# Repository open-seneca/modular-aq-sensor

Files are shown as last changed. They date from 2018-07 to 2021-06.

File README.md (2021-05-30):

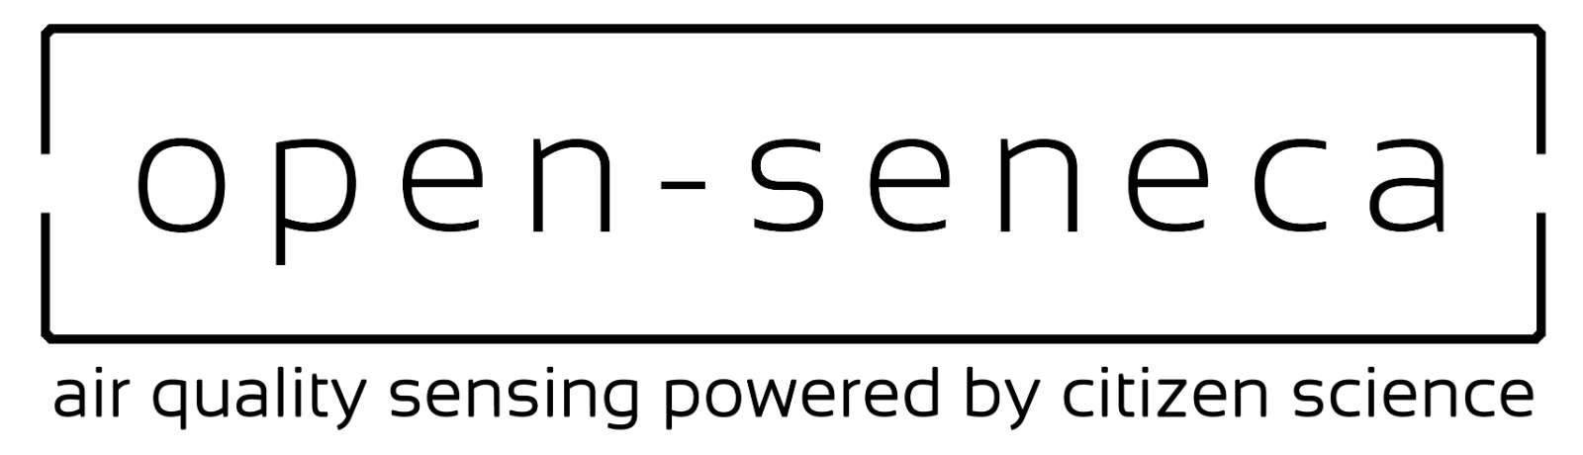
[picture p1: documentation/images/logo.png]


| PCB version | Code version | Name | Pilot date | Lifecycle |
| :---: | :---: | :---: | :---: | :---: |
| v3 | v10 | Europe 21 | current | in production |
| v2 | v8/v9 | Kenya 20 | Mar-20 | in stock |
| v1 | v7 | Argentina 19 | May-19 | discontinued |
| v0 | v4 | CamBike sensor | Aug-18 | discontinued |

Please also refer to our current, smaller, and all-integrated air quality sensor kit which is also open-source on Github: 
https://github.com/open-seneca/integrated-aq-sensor

If you already have a sensor and want to upload and visualise your data you can create an account here:
http://app.open-seneca.org

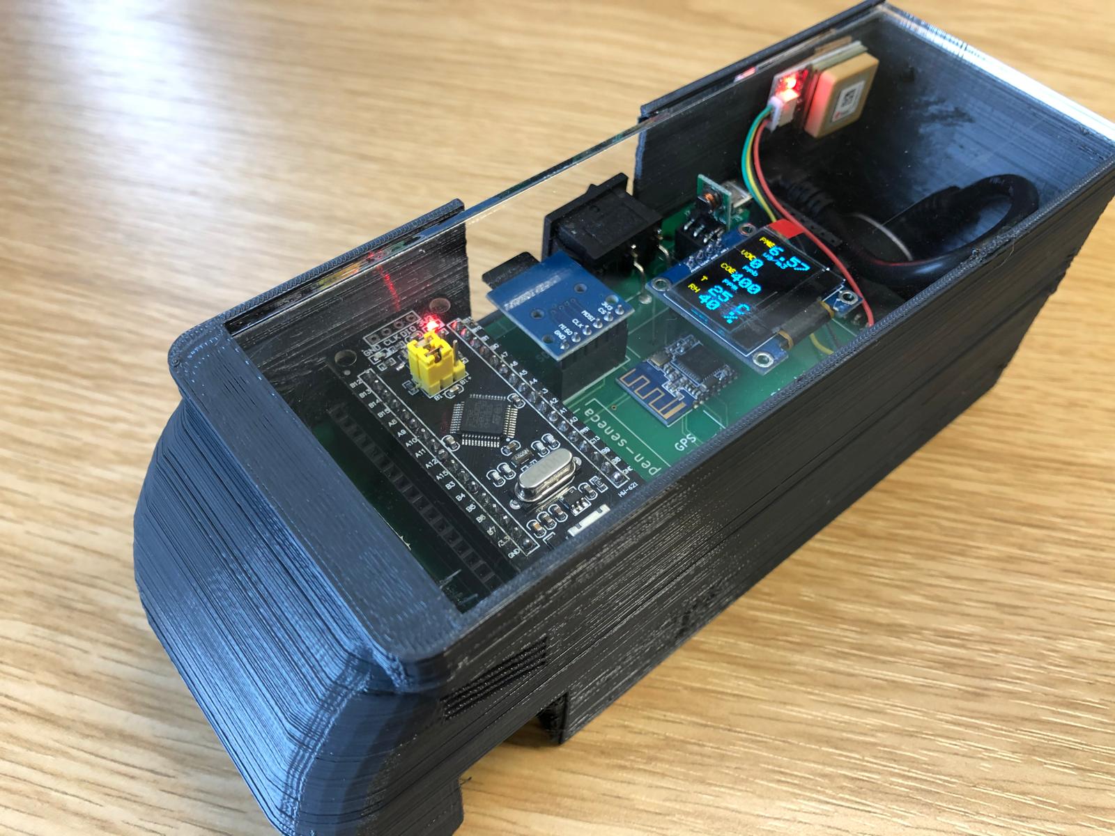
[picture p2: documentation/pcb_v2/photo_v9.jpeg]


If you have built your kit and want to flash the code to the Black Pill board, here is how:

a) Wiring and onboard jumpers:
- RX on the USB2TTL adapter to PA9, TX to PA10, GND to G, 3.3V to V3
- jumper B0+ to center pin, B1- to center pin

b) To flash the code:
- install Arduino Due in IDE board manager
- put Arduino_STM32 library (from the "hardware" folder in this repo) in "My Documents/Arduino/hardware" (Note: if the hardware folder doesn't exist you will need to create it)
- do the same for the content of the "library" folder in this repo
- start Arduino IDE and open the latest bp_vX from this repository
- under "Tools -> Board" select "Generic STM32F103C series"
- under "Tools -> Upload method" select Serial
- press reset button on the Black Pill to enter its flash mode
- click "Upload" to flash your code

c) To execute the code:
- after flashing code should run
- plug both header pins on low (B1- should be low already if your followed the steps correctly, move other jumper to B0-)
- the board will now keep its flash memory, every reset will restart execution

We are an open-source project, please feel free to extend and improve our code, just post a commit!

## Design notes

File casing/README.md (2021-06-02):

- v8 box fits the ublox GPS which has been distribuetd in Nairobi 2020 on motorbikes
- v9 3d-printed enclosure fits the modular SIM868 GSM/GPS module (display visible) which has only been used for demonstration purposes

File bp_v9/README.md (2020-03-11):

## v9 discontinues support for ublox GPS but SIM868 is now supported (GPS and GSM). For ublox GPS please flash v8

## If you experience compilation errors with v9, please check you have the TinyGSM library from this repository and acticate the 128kB memory option for the STM32 in the Arduino IDE (under 'Tools').

### Features
- SIM868 GSM wireless transmission
- HM10 Bluetooth transmission (not yet implemented in code)
- SGP30 TVOC / eCO2 sensor
- SHT31 Humidity / Temparature sensor
- SPS30 Particulate matter sensor
- Connector for UBLOX GPS
- Micro USB power plug
- 128x64 i2c OLED display

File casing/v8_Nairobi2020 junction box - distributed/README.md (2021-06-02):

# This enclosure requires a laser-cut piece (see dwg above), a USB power bank, and a junction box (examples below).

SIM868 does not fit box, use u-blox.

Plastic Electronic Project Box 158 x 90 x 60mm Junction Enclosure Case Box Waterproof w Clear Cover



Aibocn Slim Power Bank 6700mAh Portable Charger 4.3 x 1.2 x 1 inches size



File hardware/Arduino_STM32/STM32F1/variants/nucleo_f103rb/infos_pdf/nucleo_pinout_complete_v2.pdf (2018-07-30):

## left

## side

remapable | default function | Arduino | Name Pin | | Pin Name | | Arduino | default function | remapable
| TX Serial2* | D31 | PC10 | 1 | 2 | PC11 | D44 | RX Serial2*
| SDIO_CK | | PC12 | 3 | 4 | PD2 | D30 | TIM3_ETR
| | | VDD | 5 | 6 | E5V
| | | Boot0 | 7 | 8 | GND | GND
| | | NC | 9 | 10 | NC | NC
| | | NC | 11 | 12 | IORef | IoRef
| SWDIO | D41 | PA13 | 13 | 14 | RST | RST
| SWCKL | D42 | PA14 | 15 | 16 | 3,3V | 3,3V
TIM2_CH1_ETR/SPI1_SS | JTDI | D43 | PA15 | 17 | 18 | 5V | 5V
| | | GND | 19 | 20 | GND | GND
| I2C1_SDA/TIM4_CH2 | D22 | PB7 | 21 | 22 | GND | GND
| User Button | D27 | PC13 | 23 | 24 | Vin | Vin
| 32khz! | D28 | PC14 | 25 | 26 | NC
| 32khz! | D29 | PC15 | 27 | 28 | PA0 | A0/D16 | ADC12_IN0/TIM2_CH1_ETR
| OSC** | | PD0 | 29 | 30 | PA1 | A1/D17 | ADC12_IN1/TIM2_CH2
| OSC** | | PD1 | 31 | 32 | PA4 | A2/D18 | SPI1_SS/ADC12_IN4
| | | Vbat | 33 | 34 | PB0 | A3/D19 | ADC12_IN8/TIM3_CH3 | TIM1_CH2N
| ADC12_IN12 | D23 | PC2 | 35 | 36 | PC1 | A4/D20 | ADC12_IN11
| ADC12_IN13 | D24 | PC3 | 37 | 38 | PC0 | A5/D21 | ADC12_IN10

## right

## side

remapable | default function | Arduino | Name Pin | | Pin | Name | Arduino | default function | remapable
TIM3_CH4 | | D40 | PC9 | 1 | 2 | PC8 | D39 | | TIM3_CH3
I2C1_SCL | TIM4_CH3 | D15 | PB8 | 3 | 4 | PC6 | D38 | | TIM3_CH1
I2C1_SDA | TIM4_CH4 | D14 | PB9 | 5 | 6 | PC5 | D26 | ADC12_IN15
| | VDD | AVDD | 7 | 8 | U5V
| | GND | GND | 9 | 10 | NC
| LED/SPI1_SCK/ADC12_IN5 | D13 | PA5 | 11 | 12 | PA12 | D45 | USBDP TIM1_ETR
TIM1_BKIN | SPI1_MISO/ADC12_IN6/TIM3_CH1 | D12 | PA6 | 13 | 14 | PA11 | D33 | TIM1_CH4
TIM1_CH1N | SPI1_MOSI/ADC12_IN7/TIM3_CH2 | D11 | PA7 | 15 | 16 | PB12 | D34 | SPI2_SS/I2C2_SMBAl/TIM1_BKIN
| I2C1_SCL/TIM4_CH1 | D10 | PB6 | 17 | 18 | PB11 | | I2C2_SDA | TIM2_CH4

TIM3_CH2 | | D9 | PC7 | 19 | 20 | GND
| TX Serial/TIM1_CH2 | D8 | PA9 | 21 | 22 | PB2 | D46 | Boot1
| TIM1_CH1/MCO | D7 | PA8 | 23 | 24 | PB1 | D32 | ADC12_IN9/TIM3_CH4 | TIM1_CH3N
TIM2_CH3 | I2C2_SCL | D6 | PB10 | 25 | 26 | PB15 | D37 | SPI2_MOSI/TIM1_CH3N
TIM3_CH1/SPI1_MISO | | D5 | PB4 | 27 | 28 | PB14 | D36 | SPI2_MISO/TIM1_CH2N
/SPI1_MOSI TIM3_CH2 | I2C1_SMBAl | D4 | PB5 | 29 | 30 | PB13 | D35 | SPI2_SCK/TIM1_CH1N
/SPI1_SCK TIM2_CH2 | RX Serial /SWO** | D3 | PB3 | 31 | 32 | AGND
| RX Serial/TIM1_CH3 | D2 | PA10 | 33 | 34 | PC4 | D25 | ADC12_IN14
use desolder jumper for | TX Serial1**/ADC12_IN2/TIM2_CH3 | D1 | PA2 | 35 | 36 | NC
desolder jumper for use | RX Serial1**/ADC12_IN3/TIM2_CH4 | D0 | PA3 | 37 | 38 | NC

*SW

remapped | 5V
Tolerant | Arduino
Header

### **solder

mod | | Arduino
pin

NR
!

### not

in

use | Dxx | save
to

use?

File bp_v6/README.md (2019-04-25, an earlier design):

## Important: bp_v6 is our new Kenya prototype and currently not compatible with the old PCB on which this GihHub documentation is based on. This is a work in progress.

### New features
- SIM800L GSM wireless transmission
- HM10 Bluetooth transmission (not yet implemented in code)
- SHT31 Humidity / Temparature sensor
- SPS30 Particulate matter sensor
- Connector for UBLOX GPS
- Micro USB power plug

### Discontinued functions
- Accelerometer / Gyroscope
- LoRa wireless transmission

The measured power draw is around 70-90mA (while GSM is not trasmitting) at 5V supply, ~0.4W.
With a 10.000mAh powerbank you can keep the sensor running for about 5 days constantly (ideal conditions).

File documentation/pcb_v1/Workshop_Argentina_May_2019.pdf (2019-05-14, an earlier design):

# WORKSHOP ARGENTINA

## 1.0 MATERIALS AND COMPONENTS

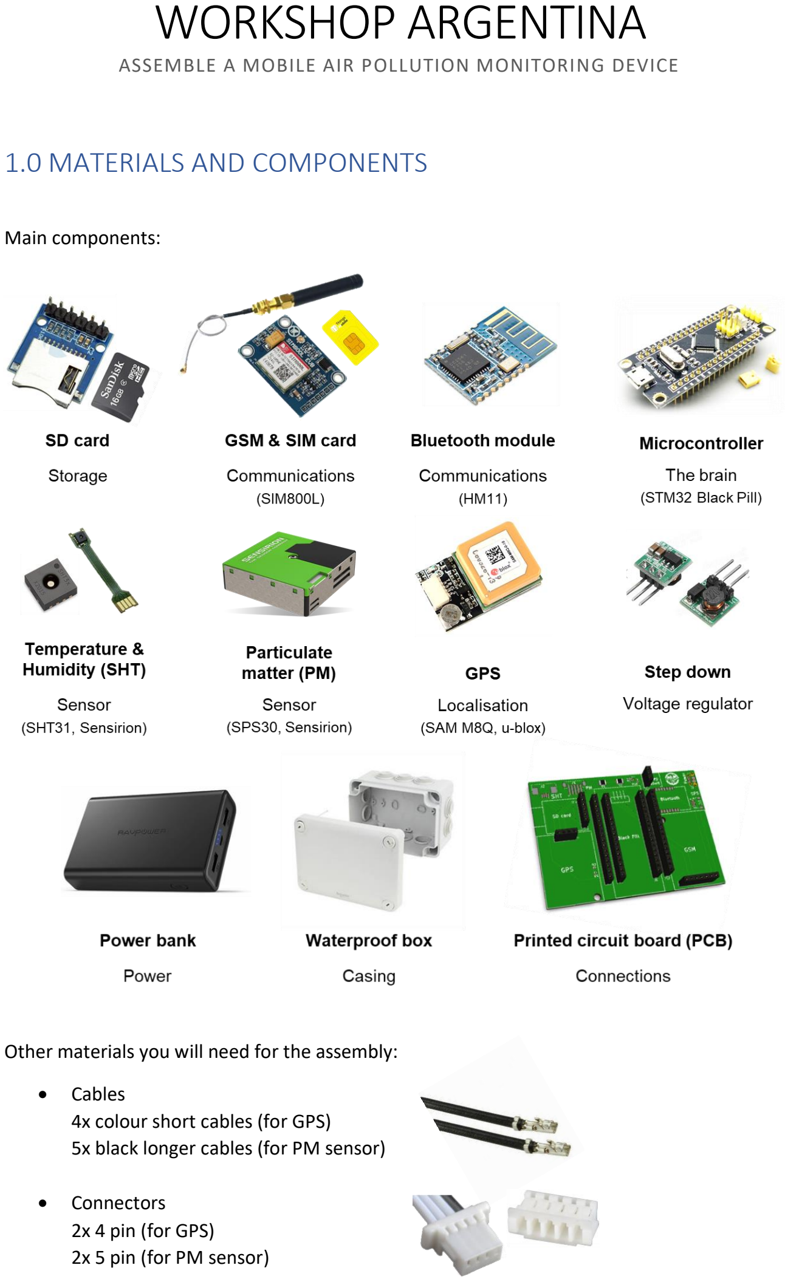
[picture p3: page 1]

ASSEMBLE A MOBILE AIR POLLUTION MONITORING DEVICE

Main components:

Other materials you will need for the assembly:

- Cables
4x colour short cables (for GPS)
5x black longer cables (for PM sensor)
- Connectors
2x 4 pin (for GPS)
2x 5 pin (for PM sensor)

- Fixing materials
Foam
Velcro
Cable ties

## 2.0 ASSEMBLY

1. Have a look to the printed circuit board (PCB). You should see the name of each of the components next to the place where they should be plugged in, either directly or through a connector.
Ask if you have any doubts about which component is which or how to connect them!

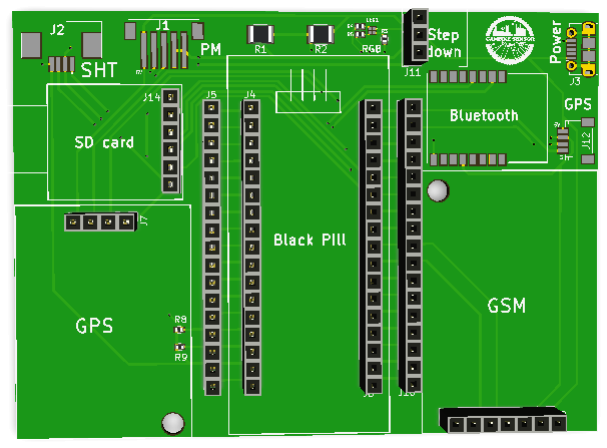
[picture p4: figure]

2. Start plugging the components that have pins into the black pin sockets. You should plug in:
a) the Black Pill microcontroller (check in which direction following the drawing on the PCB!)
b) the GSM module
c) the step-down voltage regulator
d) the SD card module

The only module that is not plugged in is the GPS. Don’t forget to put the SD card in the SD card module and the SIM card in the GSM module! Plug in the GSM antenna as well.

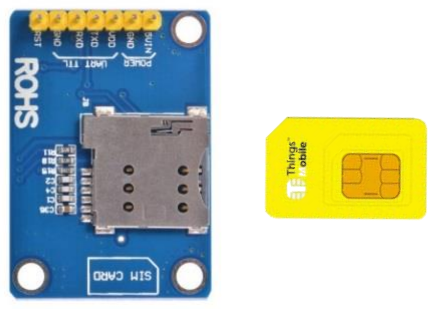
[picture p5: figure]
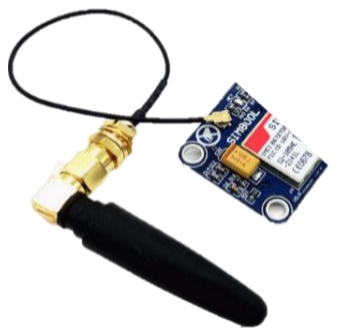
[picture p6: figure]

3. Prepare the connectors for the GPS and the PM sensors:

Connecting the GPS

Plug the white connector into the GPS and then plug the red cable into the connector where it says 5V. You should feel a “click” when the red cable is properly connected. Make sure you plug the cable in the connector in the correct orientation- the small metal protrusion should be aligned with the narrow end of the white connector, as indicated by the green arrows in the diagram. If in doubt, ask to check before plugging it in!

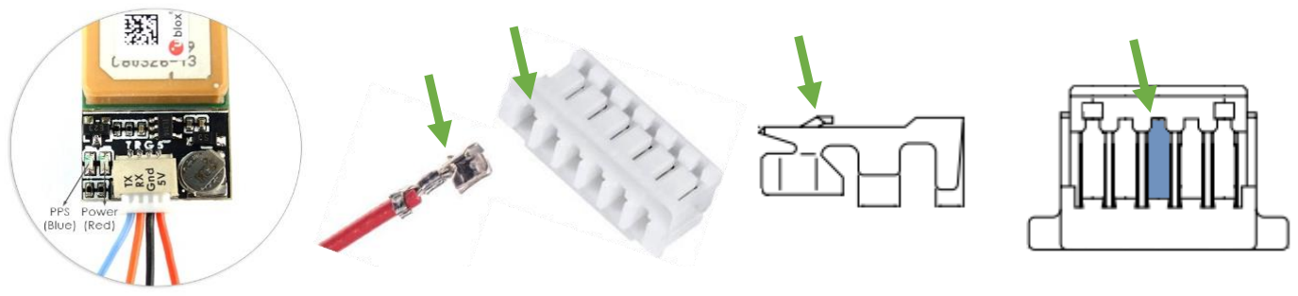
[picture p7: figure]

Do the same at the other end of the cables, plugging the second white connector into the PCB board first and then plugging the red cable in the side of the connector where 5V is written on the board, as shown below.

Plug the rest of the cables into the connectors, following the same order: black for ground (GND) and two colours of your choice for the communication pins (TX and RX).

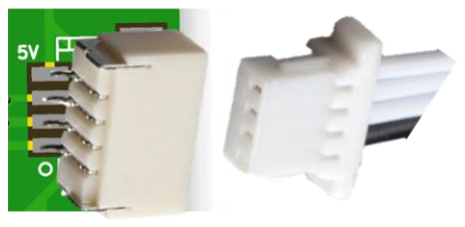
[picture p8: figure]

Connecting the PM sensor

Following the same procedure as for the GPS, plug the white 5 pin connector to the PM sensor. Pin 1 (to the left) is the 5V pin. Connect the cable and plug it to connector on the PCB, where 5V is written on the board. Then follow the same order for the rest.

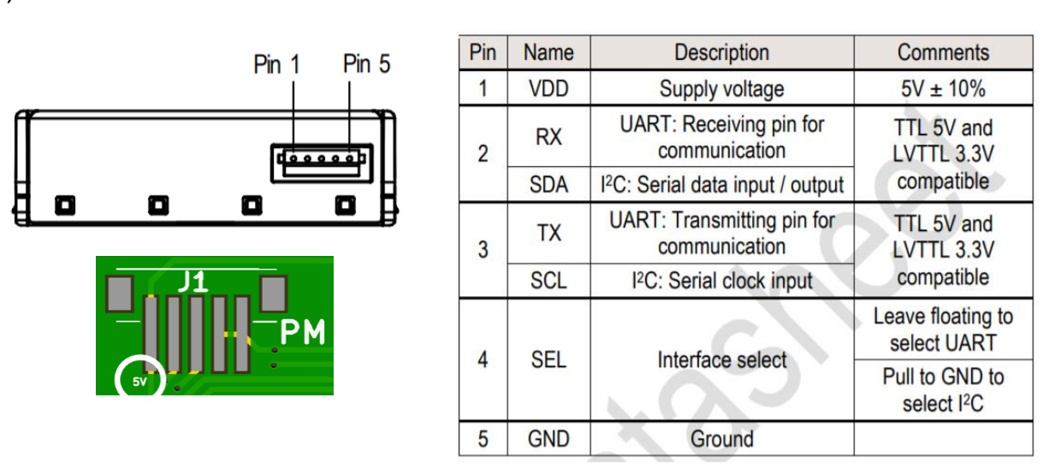
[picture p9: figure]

Datasheet of Sensirion SPS30 PM sensor

4. Connect the temperature and humidity sensor:

Slide the black part of the connector out and clip the humidity sensor in it with the pads looking up. Then reinsert the black connector so the pads are held in place.

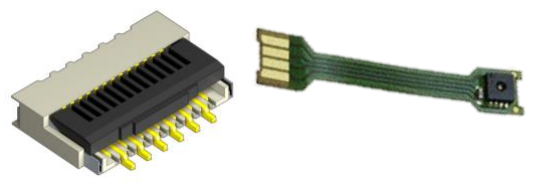
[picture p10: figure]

5. Plug in the power bank using the micro USB cable.
6. Open box and place components inside.

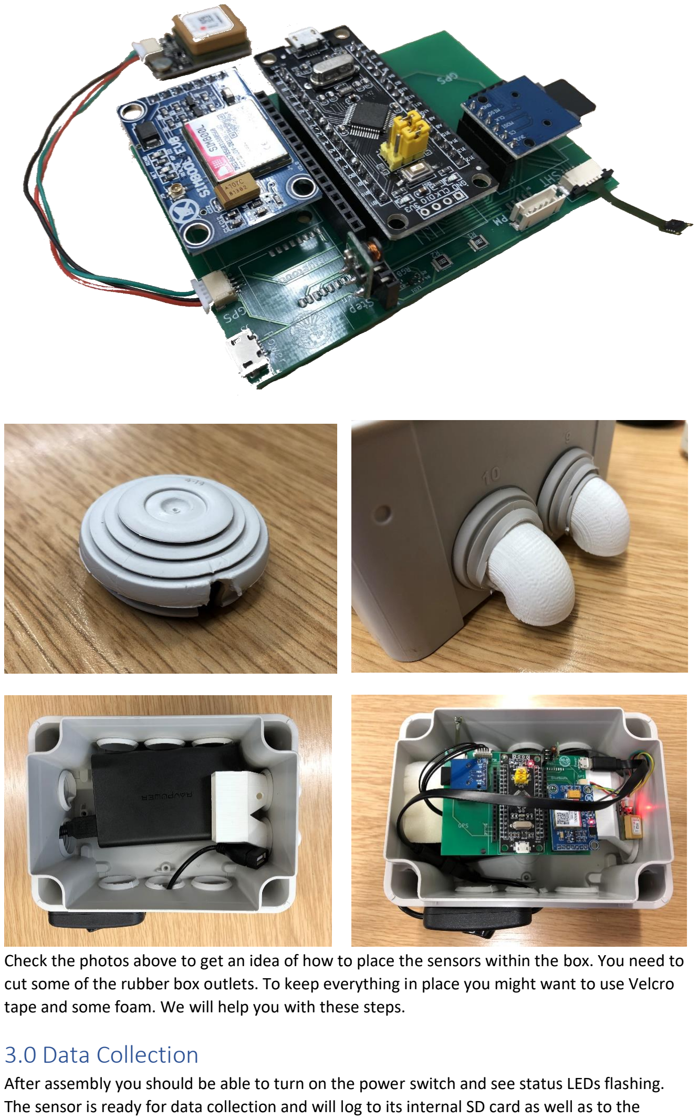
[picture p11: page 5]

Check the photos above to get an idea of how to place the sensors within the box. You need to cut some of the rubber box outlets. To keep everything in place you might want to use Velcro tape and some foam. We will help you with these steps.

## 3.0 Data Collection

After assembly you should be able to turn on the power switch and see status LEDs flashing. The sensor is ready for data collection and will log to its internal SD card as well as to the server via GSM. Using the 10.000mAh battery we provide it should be able to run up to 5 days continuously with 1 full charge.

## 4.0 Data Uploading and Analysis

### User creation and accessing the file manager

- Go onto http://app.open-seneca.org
- Click on the link for registration in order to get a user
- Choose a username (special characters are not allowed)
- If SIM card data later is desired, a SIM card number must be provided in the registration form
- Once the registration is complete, you will be forwarded to the file manager that is also linked to at http://app.open-seneca.org
- Log in using your newly created user

### Uploading data and visualising

After entering the file manager, the interface below will be shown

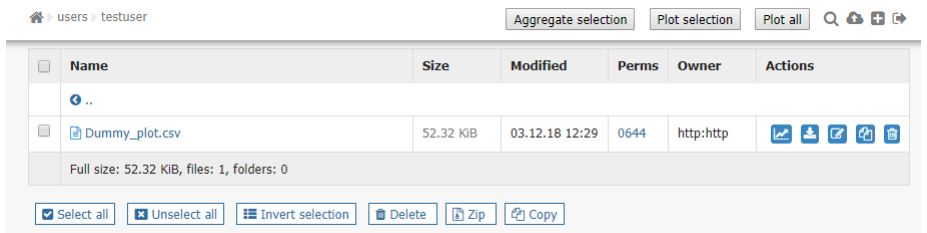
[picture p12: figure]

In the upper right corner, there are buttons (from right to left) to sign out, create a folder and upload data. Clicking the button to upload brings up the following panel:

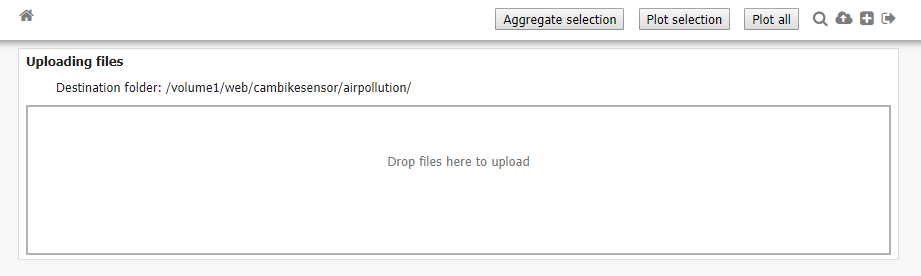
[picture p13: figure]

Clicking the panel allows selection of local files in a file dialogue for uploading. Alternatively, one or more files can be dragged from a folder on your PC and dropped into the panel to upload them.

In the file manager interface every file has an associated set of buttons:

These do the following (from right to left): plot the data from the file, download the file, rename the file, copy the file and delete the file.

If a plot of multiple files is desired, the buttons in the top “Aggregate selection”, “Plot selection” and “Plot all” should be used. A selection is made by checking the boxes in the leftmost column of every file of interest, e.g. the following selection of three files:

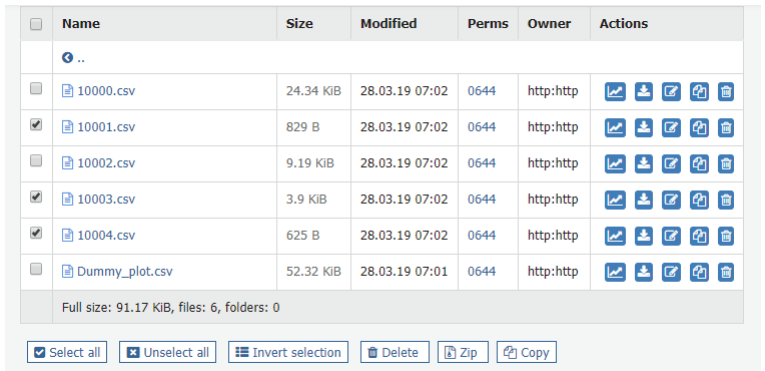
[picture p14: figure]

The “Plot selection” visualisation overlays the tracks of data on top of each other. This may be good to get an idea for how well tracks overlap as they will all be individually drawn, although the tracks may occlude each other. The “Aggregate selection” combines the data in the files to come up with an best estimate for the covered area – below is an example.

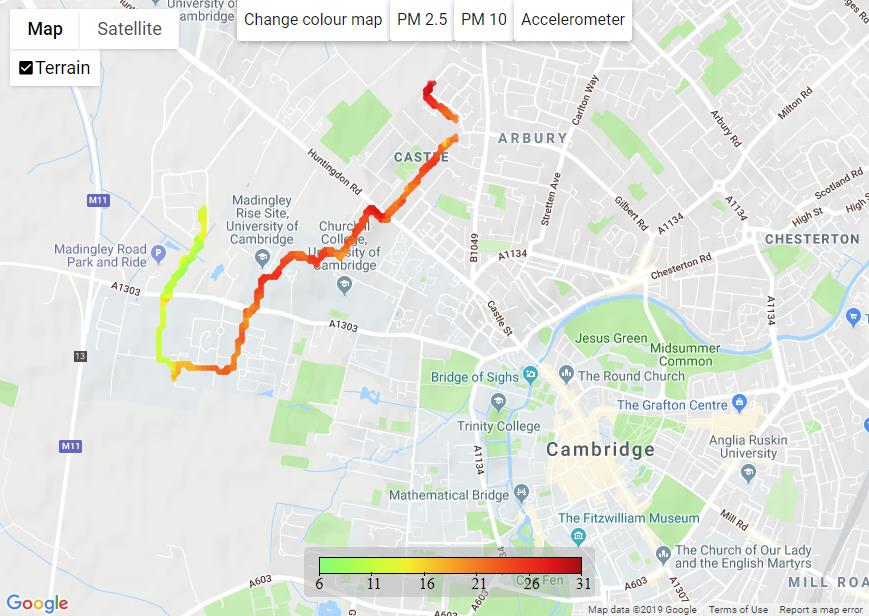
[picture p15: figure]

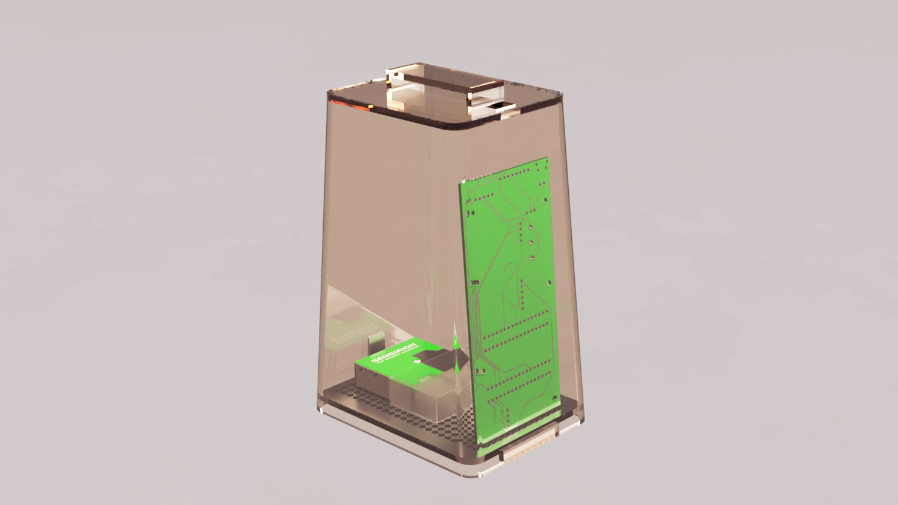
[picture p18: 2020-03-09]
casing/cowbell_v3/back_cowbell.jpg

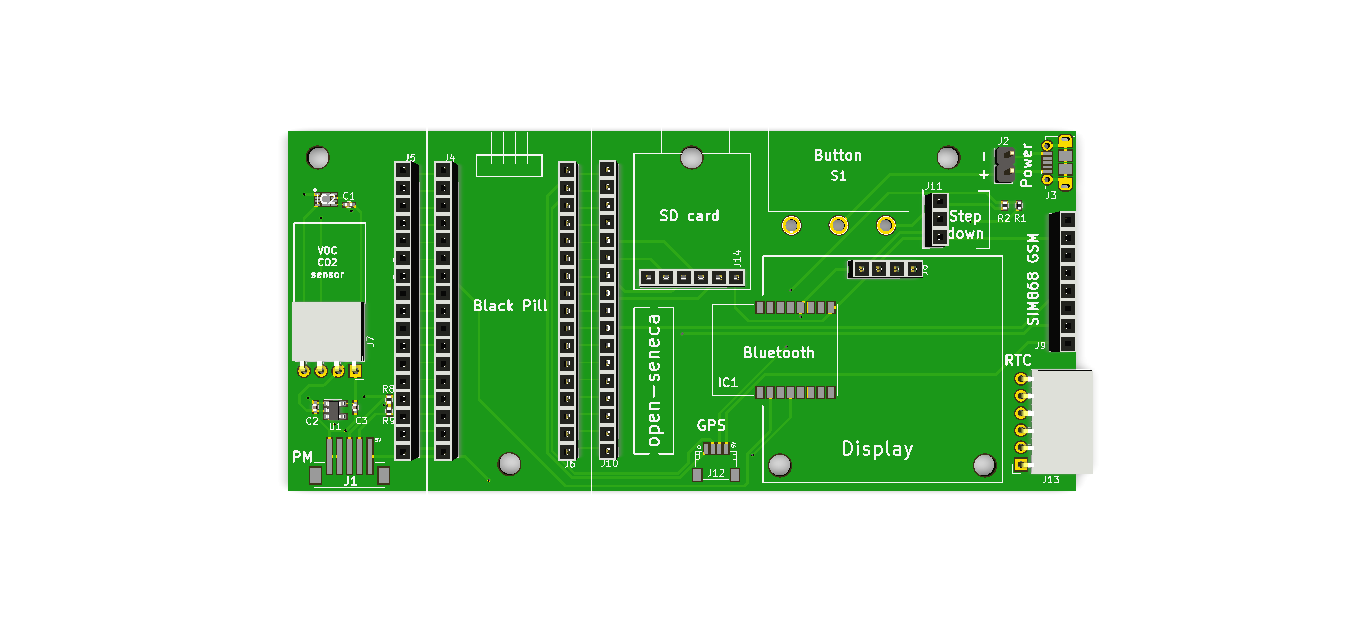
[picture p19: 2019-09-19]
pcb files/v2/PCB.png

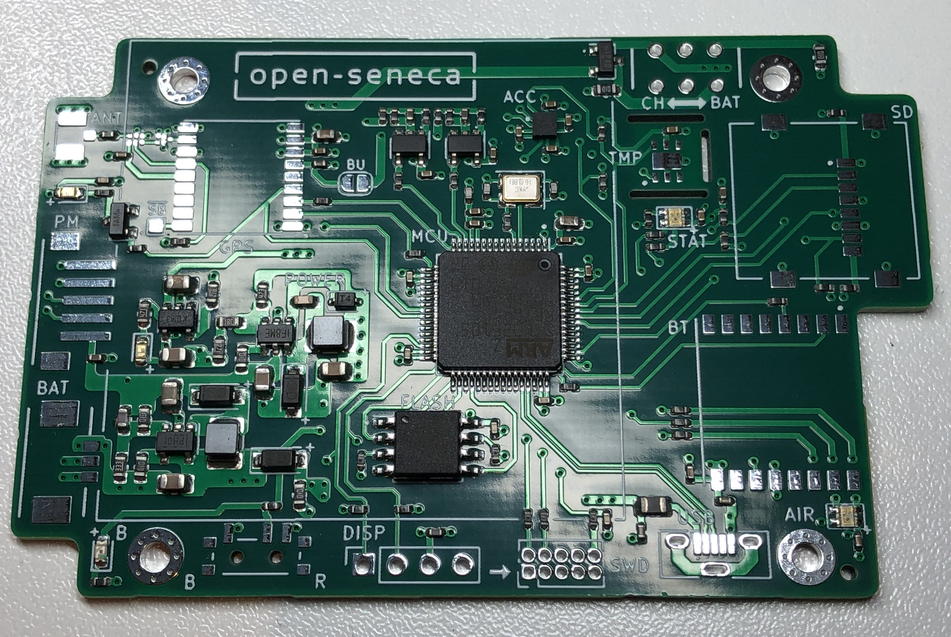
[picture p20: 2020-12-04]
documentation/pcb_v3/pcb.png

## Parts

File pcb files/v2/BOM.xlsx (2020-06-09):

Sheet: PCB Specification
fill in your PCB specification in yellow column
PCB Quantity | 50 pcs
Layer | 2 layer
PCB Thickness | 1.6 mm
Dimensions | 116.65 mm * 53.3 mm
Castellated Hole | No
PCB Color | Green
Surface Finish | HASL Lead Free
Copper Weight | 2oz
Text Color | White
Different Design | 1
Please find more PCB information on our on-line PCB ordering Page
https://www.elecrow.com/pcb-manufacturing.html

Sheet: bill of materials
BOM, fill your information in purple column
S/N | designator | quantity per PCB | manufacturer part number | description | comment or link
1 | IC2 | 1 | SHT31-DIS-B | SENSIRION - Temperature and Humidity Sensor, SHT Series, , 0% to 100% RH, 2 %, 2.4 to 5.5 V, Digital Output | https://uk.farnell.com/sensirion/sht31-dis-b/humidity-temp-sensor-digital-dfn/dp/2474218?st=SHT31-DIS-B
2 | J7 | 1 | SSW-104-02-G-S-RA | Right Angle, 2.54 mm, 4 Contacts, Receptacle, SSW Series, Through Hole | Flexible for substitutions if other provider is cheaper
3 | J8 | 1 | A2541HWV-4P | 2.54 mm, 4 Contacts, Straight, Receptacle, Through Hole, 1 Rows | Flexible for substitutions if other provider is cheaper
4 | C2,C3 | 2 | MC0402X105K6R3CT | SMD Multilayer Ceramic Capacitor, 1 µF, 0402 | Flexible for substitutions if other provider is cheaper
5 | U1 | 1 | LP3990MF-1.8/NOPB | Linear Voltage Regulator, Fixed, Linear Voltage, 2V To 6V In, 1.8V And 0.15A Out, SOT-23-5 | Flexible for substitutions if other provider is cheaper
6 | J1 | 1 | A1501WV-S-5P | CONN HEADER SMD 5POS 1.5MM | Flexible for substitutions if other provider is cheaper
7 | R1, R2, R8, R9 | 4 | MCWR04X4701FTL | SMD Chip Resistor, 0402 [1005 Metric], 4.7 kohm, MCWR Series, 50 V, Thick Film, 62.5 mW | Flexible for substitutions if other provider is cheaper
8 | J4, J6 | 2 | M20-7821746 | CONN RCPT 17POS 0.1 TIN PCB | Flexible for substitutions if other provider is cheaper
9 | J14 | 1 | A2541HWV-6P | 2.54 mm, 6 Contacts, Straight, Receptacle, Through Hole, 1 Rows | Flexible for substitutions if other provider is cheaper
10 | J12 | 1 | SM04B-SRSS-TB(LF)(SN) | CONN HEADER SMD R/A 4POS 1MM | Flexible for substitutions if other provider is cheaper
11 | IC1 | 1 | CBLE2540HM | Bluetooth Low Energy Module HM11- CC2541 | https://www.elecrow.com/bluetooth-low-energy-module-hm11-cc2540-p-859.html
12 | S1 | 1 | COM-08837 | Rocker Switch - SPST (right-angle) | https://www.sparkfun.com/products/8837
13 | J11 | 1 | A2541HWV-3P | 2.54 mm, 3 Contacts, Straight, Receptacle, Through Hole, 1 Rows | Flexible for substitutions if other provider is cheaper
14 | J2 | 1 | 2211S-02G | Vertical, 2.54 mm, 2 Contacts, Header, 2211S Series, Through Hole, 1 Rows | Flexible for substitutions if other provider is cheaper
15 | J3 | 1 | 105017-0001 | CONN RCPT USB2.0 MICRO B SMD R/A | Flexible for substitutions if other provider is cheaper
16 | J9 | 1 | A2541HWV-8P | 2.54 mm, 8 Contacts, Straight, Receptacle, Through Hole, 1 Rows | Flexible for substitutions if other provider is cheaper
17 | J13 | 1 | 613006143121 | 2.54 mm, 6 Contacts, Receptacle, WR-PHD Series, Through Hole, 1 Rows | Flexible for substitutions if other provider is cheaper
18 | C1 | 1 | GRM155R71C104KA57D | SMD Multilayer Ceramic Capacitor, 100 nF, 0402 | Flexible for substitutions if other provider is cheaper
 | Note: J5, J10 stay unpopulated

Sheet: Position File
Position File, fill your information in blue column
Designator | Footprint | Center-X(mm) | Center-Y(mm) | Rotation | Layer
C1 | C_0402 | 112.0775 | -85.5980 | 0.0000 | top
C2 | C_0402 | 107.1245 | -115.5700 | 270.0000 | top
C3 | C_0402 | 113.0300 | -115.6335 | 270.0000 | top
IC1 | HM-11-MODULE | 172.9423 | -113.4427 | 90.0000 | top
IC2 | SON50P250X250X90-9N-D | 108.6485 | -84.8360 | 0.0000 | top
J1 | B5B-ZR-SM4-TF | 112.1727 | -125.1902 | 180.0000 | top
J3 | USB_Micro-B_Molex-105017-0001 | 217.8050 | -79.3750 | 90.0000 | top
J12 | JST_SH_SM04B-SRSS-TB_04x1.00mm_Angled | 166.4335 | -123.6980 | 0.0000 | top
R1 | R_0402 | 211.2645 | -85.7250 | 270.0000 | top
R2 | R_0402 | 209.1690 | -85.7250 | 90.0000 | top
R8 | R_0402 | 118.0465 | -114.4905 | 270.0000 | top
R9 | R_0402 | 118.0465 | -116.1415 | 90.0000 | top
U1 | SOT-23-5 | 110.0455 | -116.0145 | 0.0000 | top

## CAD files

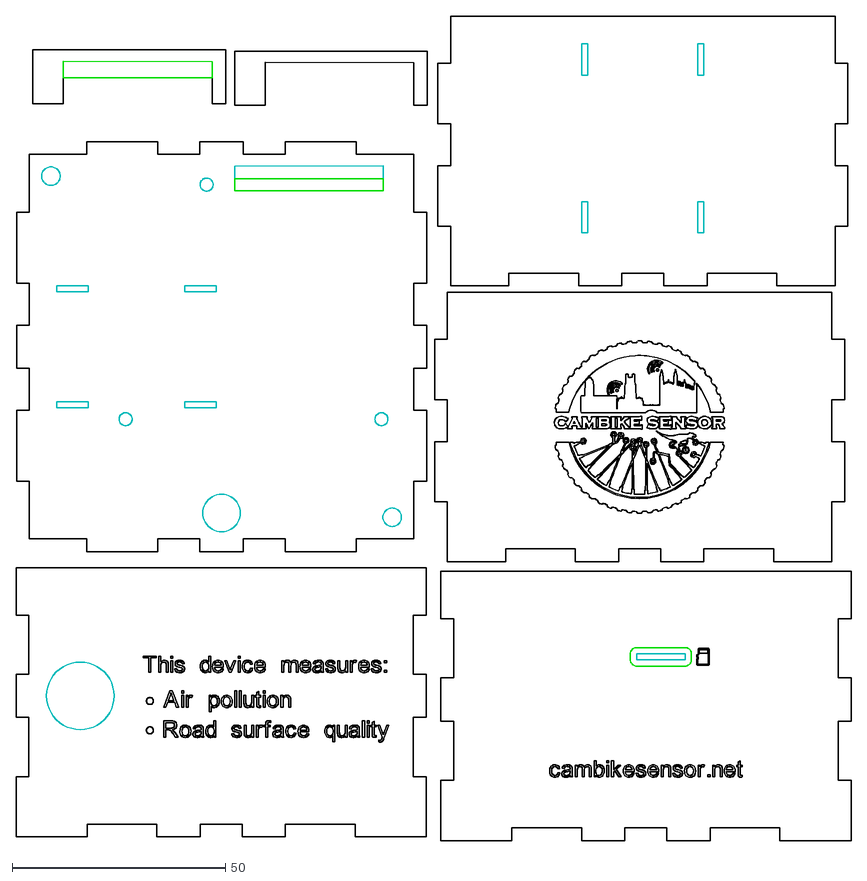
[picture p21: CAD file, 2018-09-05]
casing/Laser_cut_makespace/whole-w_out_lid.dxf
195.8 x 193.2

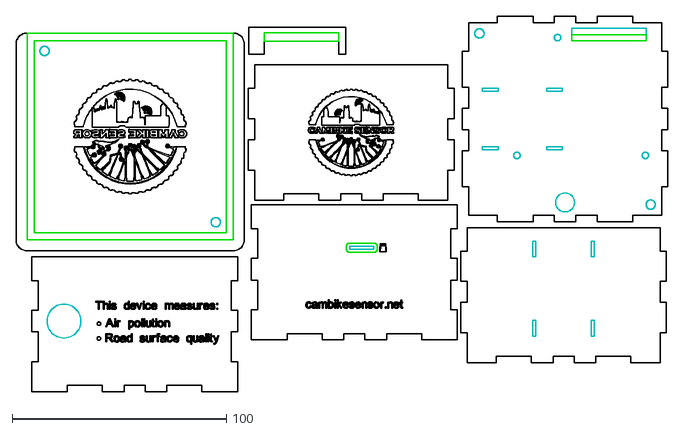
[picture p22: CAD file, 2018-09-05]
casing/Laser_cut_makespace/whole.dxf
304.6 x 175.6

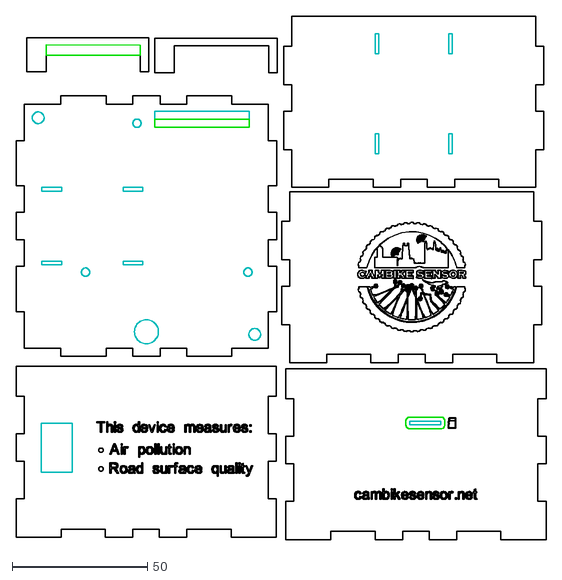
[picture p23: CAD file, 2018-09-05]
casing/Laser_cut_makespace/whole-w_out_lid_new_button.dxf
195.8 x 193.2

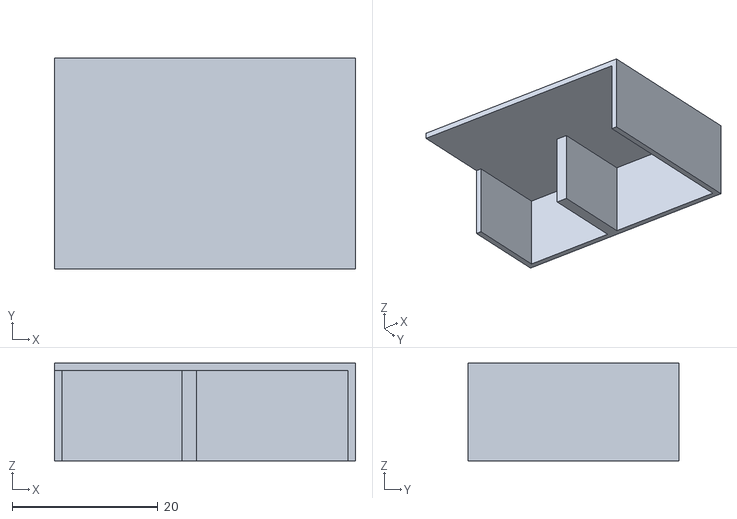
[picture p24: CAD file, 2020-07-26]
casing/Air channel/Nairobi2020/sps30housing.stl
41.3 x 29.0 x 13.4

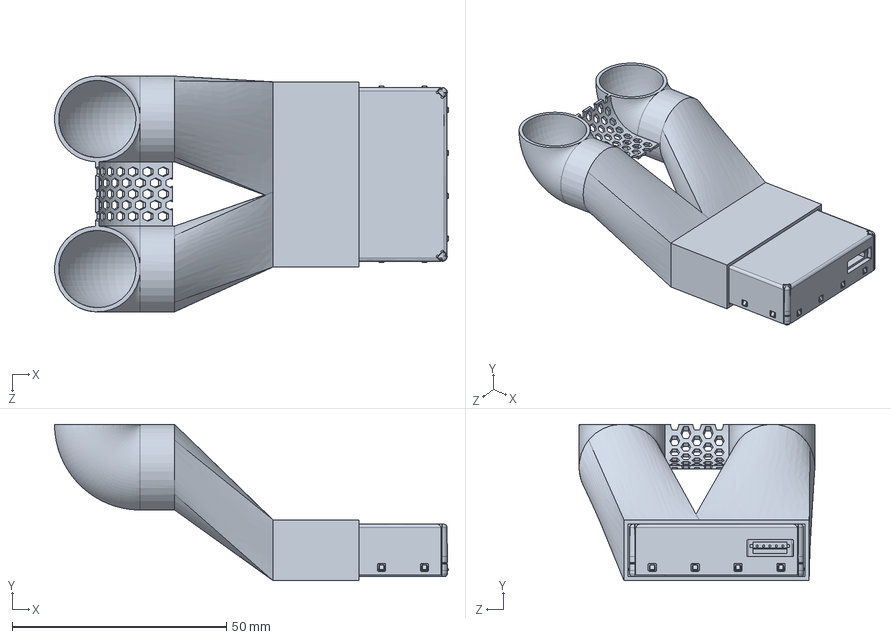
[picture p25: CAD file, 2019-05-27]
casing/Air channel/PS_CAD_SPS30_D1 v12.SLDPRT
91.9 x 36.5 x 55.0 mm

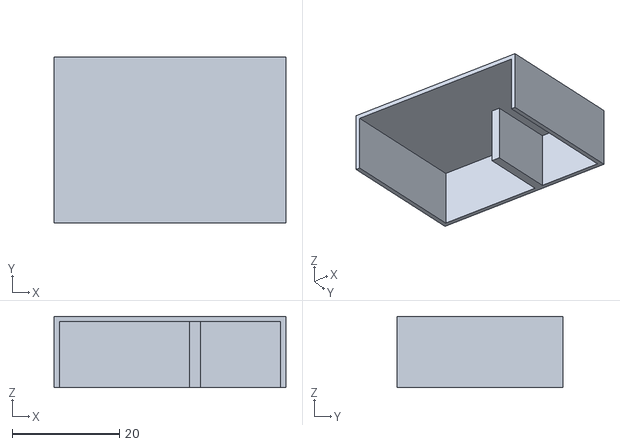
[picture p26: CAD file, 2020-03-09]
casing/cowbell_v3/sps30housing.stl
43.3 x 31.0 x 13.3

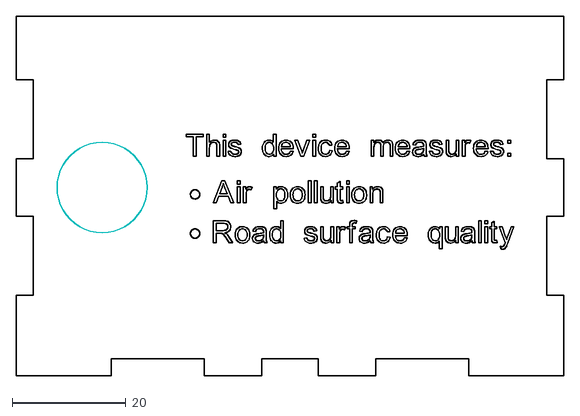
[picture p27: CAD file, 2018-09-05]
casing/Laser_cut_makespace/button_side.dxf
96.1 x 63.1

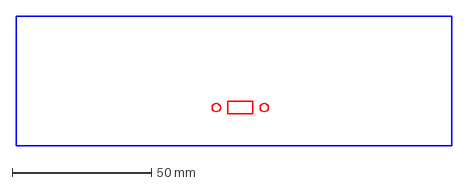
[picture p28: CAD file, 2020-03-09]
casing/Laser_cut_Nairobi2019/a_sense_board_side_final_3005.dxf
156.5 x 46.4 mm

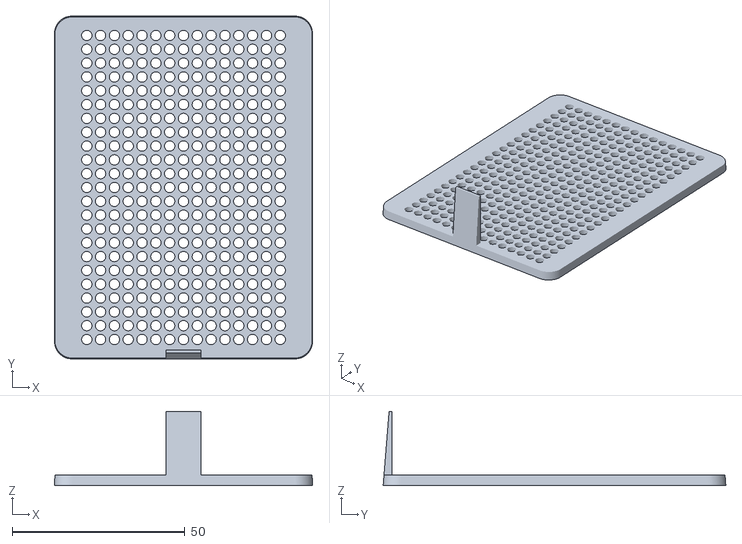
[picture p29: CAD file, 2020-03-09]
casing/cowbell_v3/bottom.stl
74.7 x 99.2 x 21.5

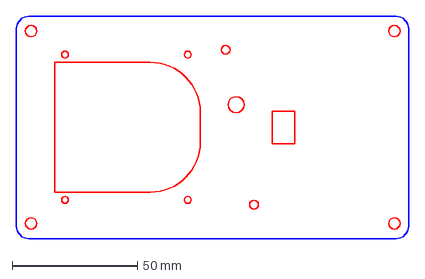
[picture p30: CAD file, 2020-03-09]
casing/Laser_cut_Nairobi2019/a_sense_board_final_3005.dxf
156.5 x 88.7 mm

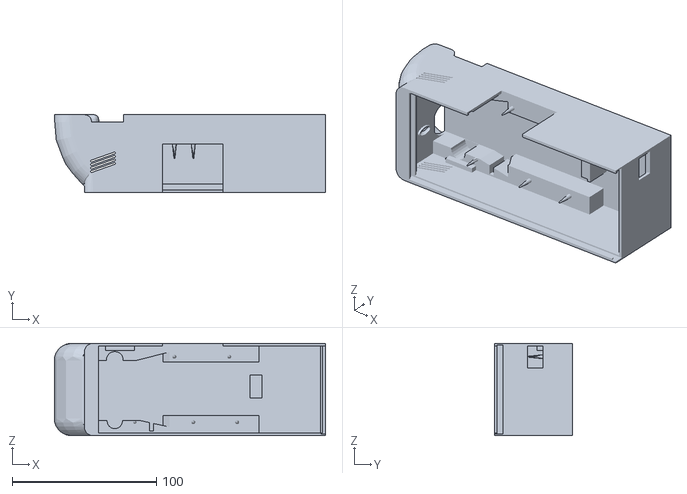
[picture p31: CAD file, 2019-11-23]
casing/v9_Nairobi2020 3d-print/v1_Versatil_Nairobi_PM_under_Tsensor_flat_2.stl
187.9 x 53.9 x 64.0

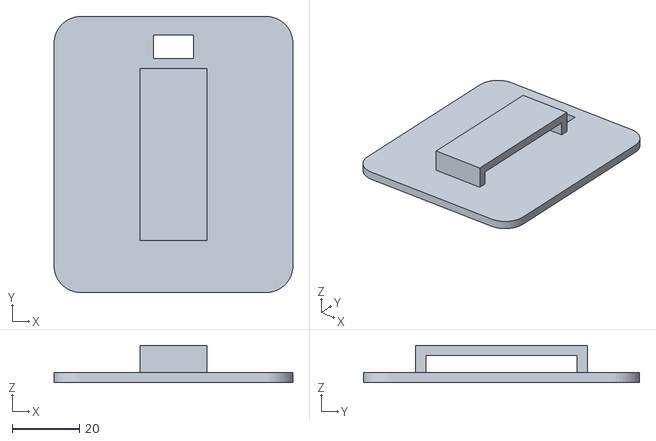
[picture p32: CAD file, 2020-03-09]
casing/cowbell_v3/lid.stl
71.0 x 82.0 x 11.0

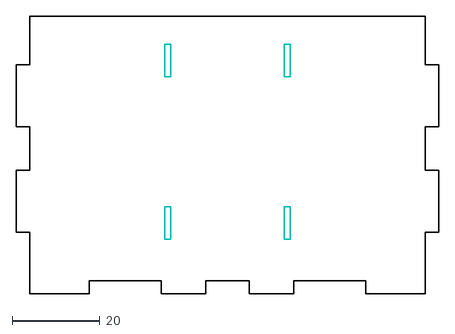
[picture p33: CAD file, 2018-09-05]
casing/Laser_cut_makespace/cable_tie_side.dxf
96.1 x 63.1

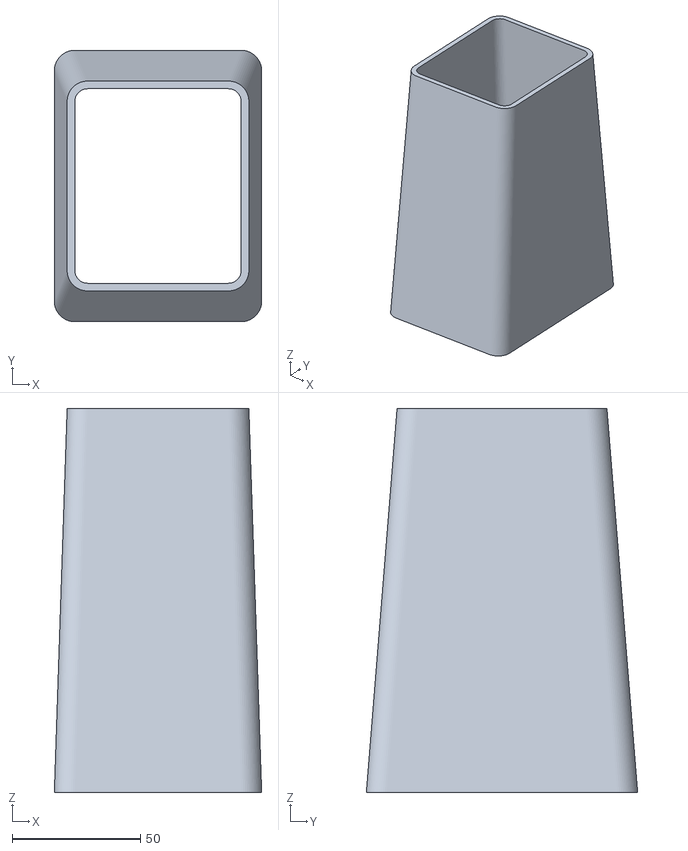
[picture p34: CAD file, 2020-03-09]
casing/cowbell_v3/shell.stl
81.0 x 106.0 x 150.0

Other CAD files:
casing/v8_Nairobi2020 junction box - distributed/a_sense_board_side_final_3005_final_v6.dwg
casing/Laser_cut_makespace/logo_side.dxf
casing/Laser_cut_makespace/top.dxf
casing/Laser_cut_makespace/cover.dxf
casing/Air channel/Nairobi2020/sps30housing-withsps30 v1.f3z
casing/Laser_cut_makespace/base.dxf
casing/Laser_cut_makespace/sd_card_side.dxf
casing/cowbell_v2/body_shorter.stl
casing/cowbell_v2/lid_shorter.stl
casing/cowbell_v2/mesh_shorter.stl
casing/v9_Nairobi2020 3d-print/v2_Versatil_Nairobi_PM_under_Tsensor_flat_battery_screw_3.stl

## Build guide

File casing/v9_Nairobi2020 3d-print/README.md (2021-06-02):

# This box requires a 3d-printer, a rectangular laser-cut sliding lid, and a powerbank (example below).

SIM868 module supported.

- v0 is the bare minimum size
- v1 has space fore some extra modules
- v2 accommodates a USB powerbank as well



Poweradd Slim2 5000mAh Portable Charger (99.82 x 32.25 x 30.48 mm)



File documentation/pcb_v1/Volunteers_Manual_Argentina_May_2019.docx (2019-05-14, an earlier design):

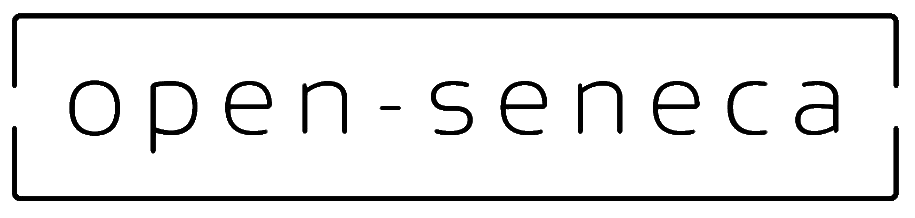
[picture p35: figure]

air quality sensing powered by citizen science

Volunteer’s manual

a) Turning the sensor on and off

If you are not actively collecting data or if you leave your bike you should turn off your sensor in order to save battery. The switch on the outside of the sensor is marked with a red dot which marks its off position.

b) Downloading data from the sensor

Open the cover marked with a red dot as indicated in the photo below. You should be able to see the SD card module to pull it out with your finger. Slide out the micro SD card and insert it into your computer. The card should contain .csv files that you can open using Microsoft Excel. The latest file is the one with the highest number (sort alphabetically). To easily visualise your data please skip to the “upload” part further down in this manual.

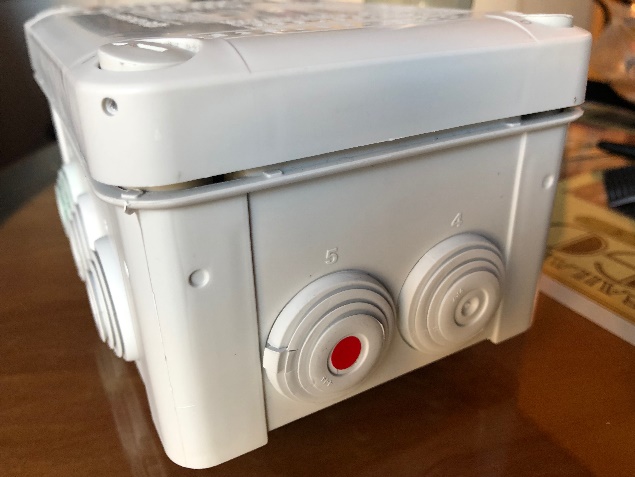
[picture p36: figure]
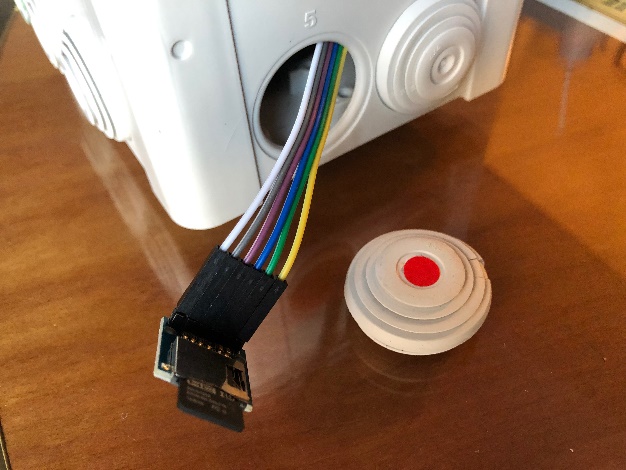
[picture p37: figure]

c) Charging the sensor

The sensor has a 10.000mAh power bank included in the case which should last for 5 days of continuous measurement. If you are only using it for a couple of bike rides per day you can use it for about a month before you have to recharge.

After pulling out the SD card you can check the number of blue LEDs lighting up on the power bank to see how much charge is left. 4 means it is full, 1 means you should recharge.

To recharge feed a micro USB cable through the hole and plug it into the power bank.

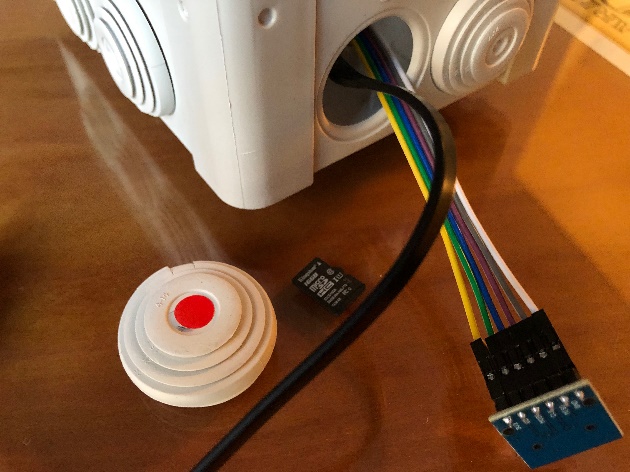
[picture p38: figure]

d) Uploading and visualising the data

User creation and accessing the file manager

- Go onto http://app.open-seneca.org
- Click on the link for registration in order to get a user
- Choose a username (special characters are not allowed)
- Once the registration is complete, you will be forwarded to the file manager
- Log in using your newly created user

Uploading data and visualising

After entering the file manager, the interface below will be shown

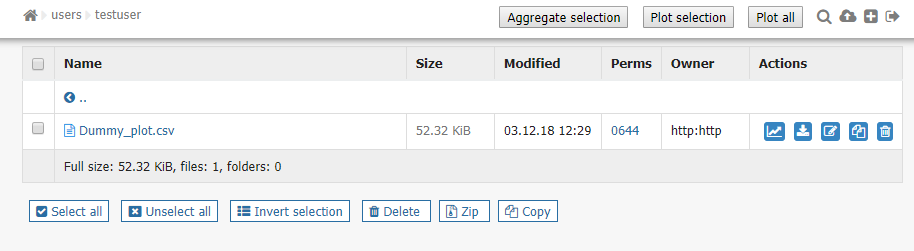
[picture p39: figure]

In the upper right corner, there are buttons (from right to left) to sign out, create a folder and upload data. Clicking the button to upload brings up the following panel:


Clicking the panel allows selection of local files in a file dialogue for uploading. Alternatively, one or more files can be dragged from a folder on your PC and dropped into the panel to upload them.

In the file manager interface every file has an associated set of buttons:

These do the following (from right to left): plot the data from the file on a map (only works when GPS location is available), plot the data versus minutes in a graph, download the file, rename the file, copy the file and delete the file.

If a plot of multiple files is desired, the buttons in the top “Aggregate selection”, “Plot selection” and “Plot all” should be used. A selection is made by checking the boxes in the leftmost column of every file of interest, e.g. the following selection of three files:

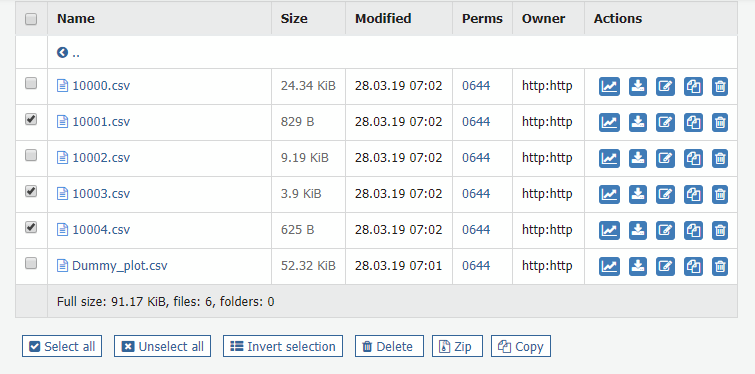
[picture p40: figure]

The “Plot selection” visualisation overlays the tracks of data on top of each other. This may be good to get an idea for how well tracks overlap as they will all be individually drawn, although the tracks may occlude each other. The “Aggregate selection” combines the data in the files to come up with an best estimate for the covered area – below is an example.

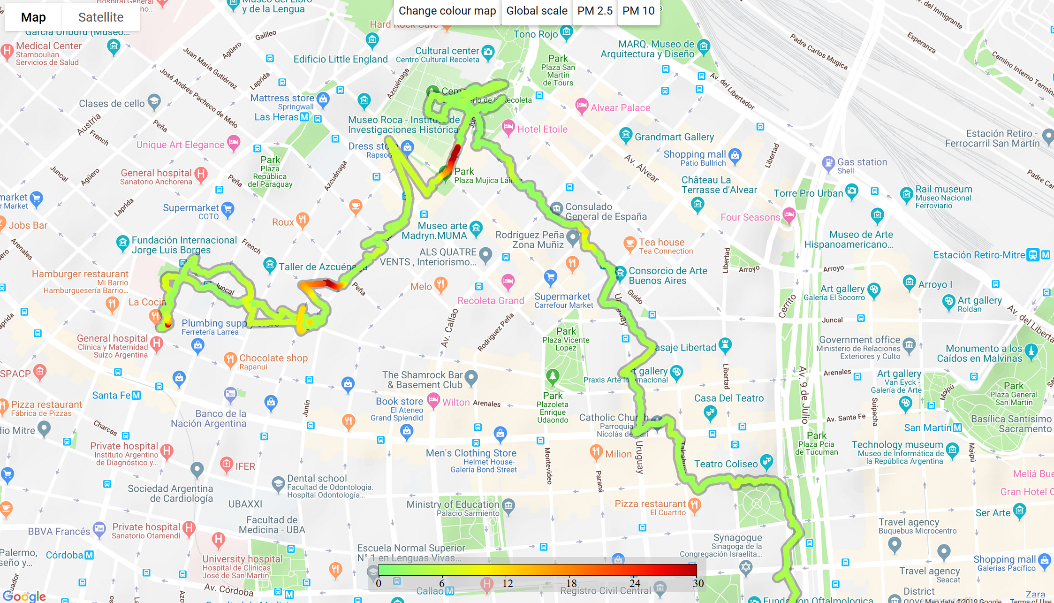
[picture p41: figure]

www.open-seneca.org

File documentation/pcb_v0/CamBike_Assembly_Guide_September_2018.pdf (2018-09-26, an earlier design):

# Assemble your CamBike Sensor hub

## Main components

Below you can find the proposed main components to build the CamBike Sensor hub. They are all off-the-shelf components that can be bought from diverse suppliers. You can find the links of the exact ones we used in our sensor hub in each entry. Feel free to get alternative ones if you prefer!

Microcontroller:
STM32F103C8T6, (https://aliexpress.com/item/STM32F103C8T6-ARM-STM32-Minimum-System-Development-Board-Module-Forarduino/32342717171.html) also known as STM32 Black Pill.

GPS:
NEO-6M V2 GPS, (https://aliexpress.com/item/1Set-Ublox-NEO-6M-GPS-Module-GY-GPS6MV2-NEO6MV2-Buit-in-EEPROM-APM2-5-Antenna-3V/32828254679.html) for geo-localisation.

Particulate Matter (PM) sensor:
SDS011, (https://www.banggood.com/Nova-PM-Sensor-SDS011-High-Precision-Laser-PM2_5-Air-Quality-Detection-Sensor-Module-p-1144246.html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) which measures PM10 and PM2.5. If you are interested in knowing more about why it is important to measure particulate matter and about how this sensor works, have a look to the Particulate Matter section!

Accelerometer and Gyroscope:
Arduino 6-axis GY-521, (https://aliexpress.com/item/GY-521-MPU-6050-MPU6050-Module-3-Axis-analog-gyro-sensors-3-Axis-Accelerometer-Module/32340949017.html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) to infer road quality.

SD card module:
Arduino-compatible SD card module (https://aliexpress.com/item/2PCS-TF-Micro-SD-Card-Module-Mini-SD-Card-Module-Memory-Module-for-Arduino-ARM-AVR/32669487176.html) to record all the data.

LoRaWAN radio:
NiceRF Lora1276, (https://aliexpress.com/item/50sets-lot-LoRa1276-long-range-4Km-868MHz-915MHz-sx1276-Radio-transceiver-Lora-modules-with-FCC-certificate/32473481271.html) for low-power wireless transmission of data. If you would like to know more about LoRaWAN and Low-Power Wide-Area Networks (LPWAN) check out this section!

Battery:
Lithium polymer flat 3.7V 1200 mAh battery (http://www.sztopenergy.com/lithium-polymer-battery/products-of-lithium-polymer-battery/lp703448-3-7v-1200mah-lithium-polymer-battery.html) with protective circuits against over-charge, over-discharge, short-circuit and over-current.

Step-up voltage regulator:
Boost from 1-5 V to 5 V, (https://aliexpress.com/item/5V-DC-DC-Converter-Step-Up-Power-Supply-DC-DC-Booster-Boost-Buck-Converter-Board-Step/32813355879.html) to increase the battery voltage from 3.7 V to 5 V. It is needed to power some of the components, such as the PM sensor.

Step-down voltage regulator:
Buck from 6-3.3 V to 3.3 V, (https://www.banggood.com/15pcs-DD0503MA-DC-3_3-6V-To-3_3V-Step-Down-Converter-Buck-Module-For-18650-ESP8266-CC1101-SI4432-p-1226186.html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) to decrease the battery voltage from 3.7 V to 3.3 V and to power most of the components.

Button LED:
RGB LED self-latching push button, (https://aliexpress.com/item/19408Z-Best-quality-power-symbol-LED-RGB-tricolor-24v-220v-19mm-metal-flat-head-latching-switches/32822281682.html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) to be used as a status LED and master switch of the hub.

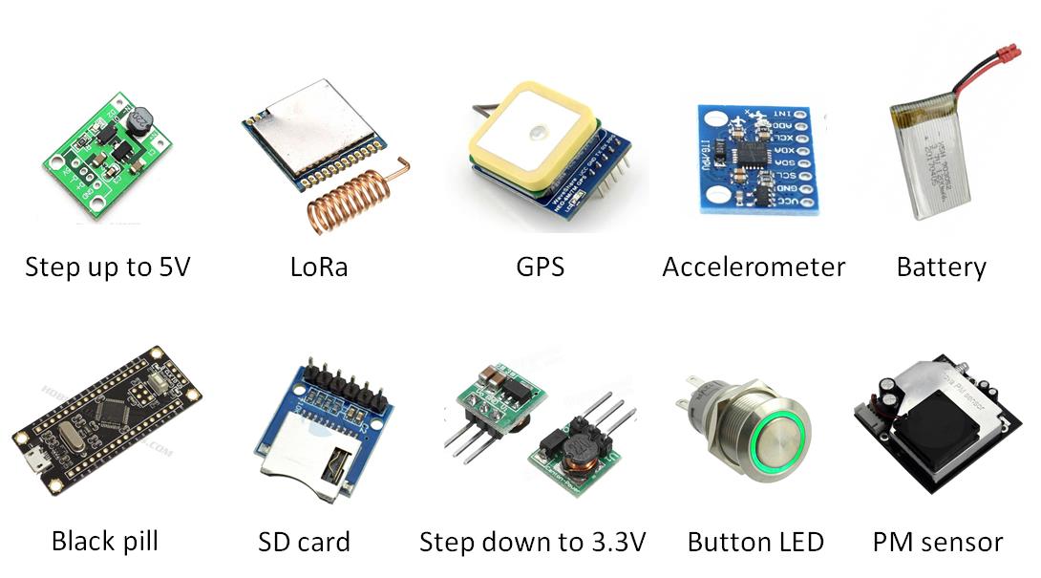
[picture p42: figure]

Most components include pin headers to be soldered in order to plug and use them. Some of them might come with the pins already soldered and some might come without pins. Therefore, be aware that you will probably need to have access to a soldering station and have some spare pin headers to work with.

## Soldering of the Printed Circuit Board (PCB)

We have designed a plug-and-play printed circuit board (PCB) that integrates all the components and fits on the top of the SDS011 PM sensor. The KiCAD files can be found in the PCB folder of our GitHub repository. (https://github.com/sh969/CambikeSensor/tree/master/PCB) You can get it printed yourself or get one of our assembly kits!

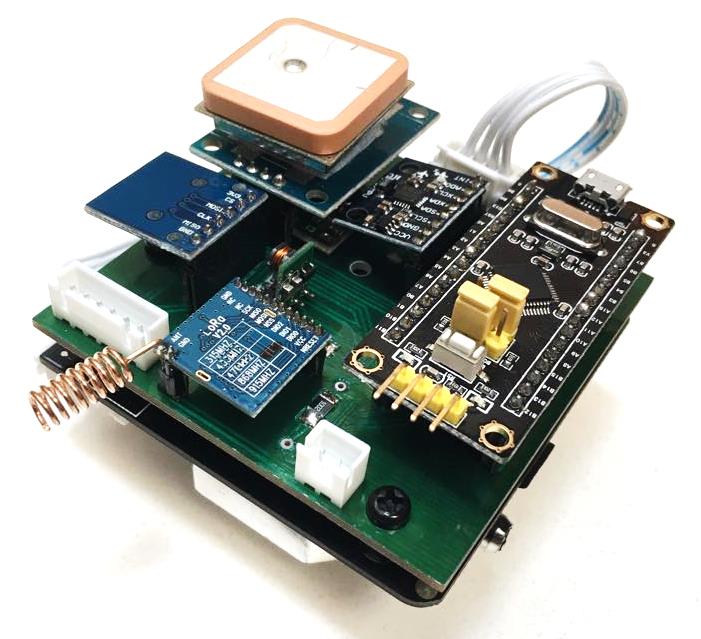
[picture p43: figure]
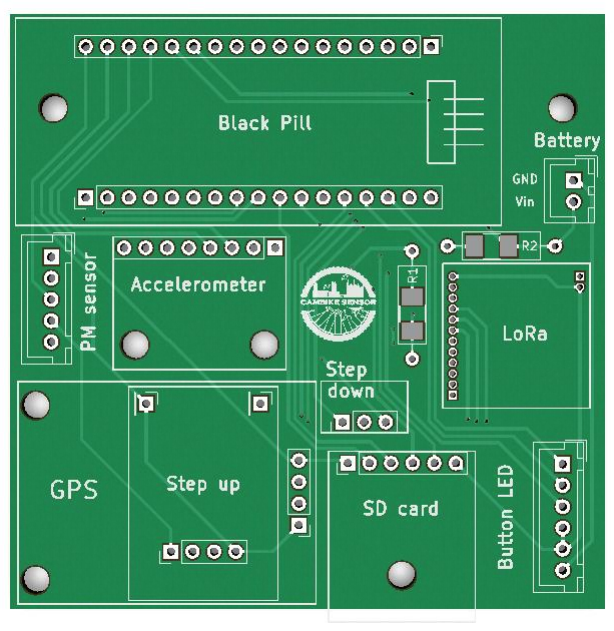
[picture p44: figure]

To mount the PCB, you will need a few more components, mainly connectors to plug the previously listed components and screws to hold the hub together. If you decided to buy an already assembled kit from us, you can skip this section.

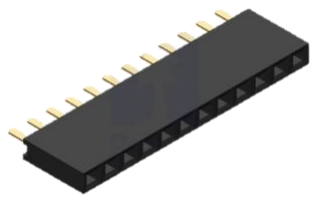
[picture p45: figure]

For one PCB, you need:

Female pin headers (pin sockets), with a pitch of 2,54 mm:

2x 17, for the Black Pill
1x 4, | for the GPS
1x 8, | for the accelerometer
1x 6, | for the SD card module

Male pin headers, with a pitch of 2,54 mm:

4x 1, for the step-up regulator

Female pins with a pitch of 1,27 mm:

1x 12
1x 2, for the LoRa radio

JST-XH connectors:

1x 2, | for the battery
1x 5, | for the PM sensor
1x 6, | for the RGB button LED

Resistors:

2x 10 kΩ
Note: As long as both are of the same value, any

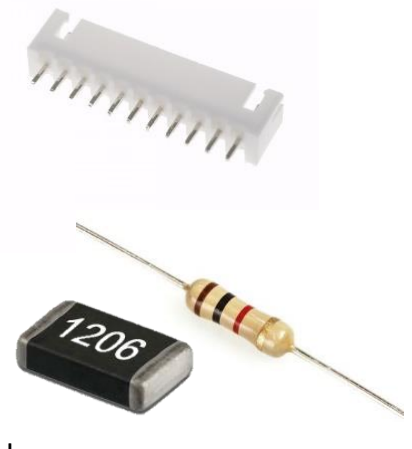
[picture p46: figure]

resistor in the order of tens of kΩ works. They can be mounted on the surface (SMD, 1206) (https://uk.rs-online.com/web/p/surface-mount-fixed-resistors/1251192/) or be conventional ones (through hole resistors).

Mounting hardware M3:

3x hexagonal 6 mm with screw 3x hexagonal 10 mm with screw 1x hexagonal 20 mm with screw 4x screws 6 mm
5x nuts

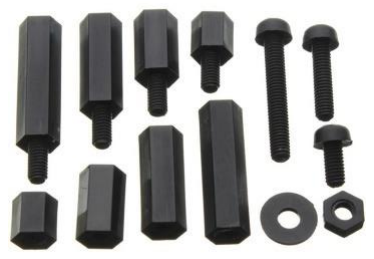
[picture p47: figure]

The text on the PCB will guide you on where to solder the pins correspondent to each of the components and where to plug them later on. As a recommendation, you can start with the resistors, and then continue with the pin headers. Make sure that you solder the pins completely perpendicular to the board, otherwise the components won’t fit later on!

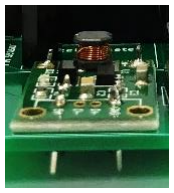
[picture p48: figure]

In order to solder the step up, we recommend soldering it directly to the
board using male pins. Introduce the male pin with the plastic bit below
the PCB, so it does not add extra height to the step up and allows it to fit underneath the GPS module. Then solder the step up to the pin as it can be seen in the picture. Use for this the four individual male pins.

Once finished, it should look like the picture below.

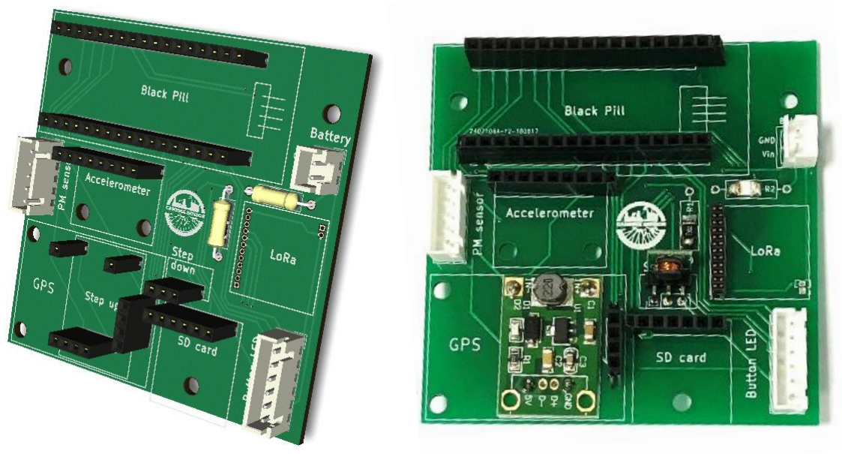
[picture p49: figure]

## Mounting the PCB

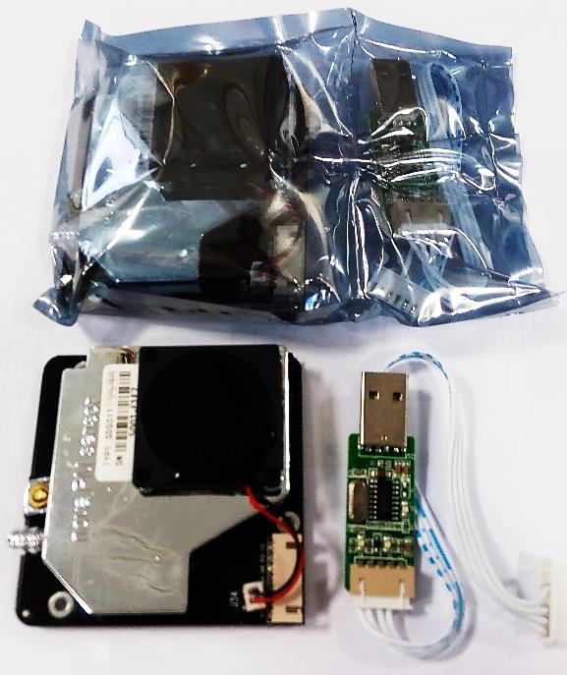
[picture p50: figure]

The PCB is mounted on the SDS011 PM sensor using three screws. As it can be seen on the picture, the PM sensor comes with an extra piece of electronics. It is a TTL Serial to USB adaptor, meant to be used to communicate the sensor with a computer by directly plugging it via an USB port. You won’t need it to plug the sensor to the PCB, but you do need the cable that comes with it. The converter will be useful later on to flash the code into the microcontroller.

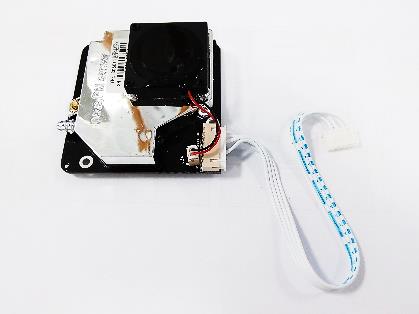
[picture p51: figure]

1. Start placing the 3x hexagonal 6mm screws on the PM sensor:

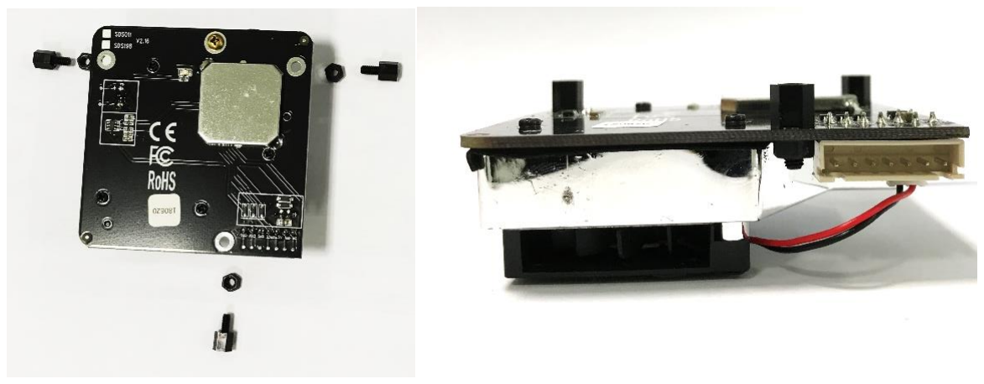
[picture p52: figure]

2. Then place the 2x hexagonal 10 mm screws on the PCB, to hold the GPS and accelerometer in place.

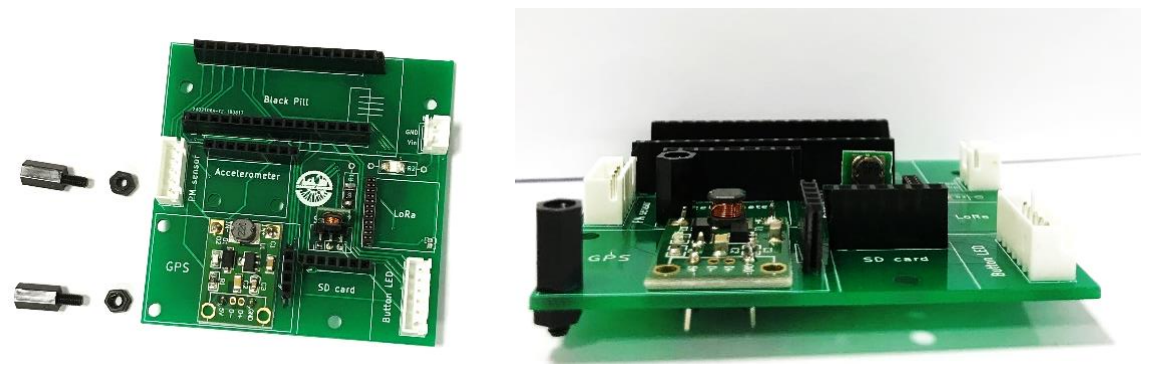
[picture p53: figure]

3. Now you can mount the PCB on the PM sensor and screw them together using 2x 6 mm screws for the upper two holes, and 1x hexagonal 10 mm screw for the bottom hole (in the SD card zone). The later will be used as a support for the SD card module.

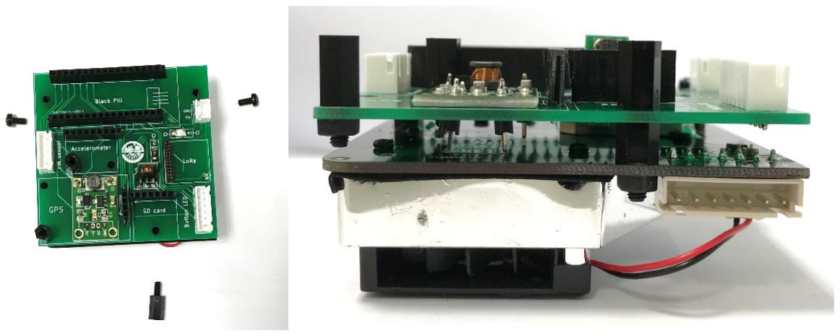
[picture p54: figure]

4. The next step is to plug all the components! Follow the text on the PCB to know where each of them should be placed. Don’t forget to plug the GPS antenna with the receiver facing up (as in the picture below). You can also hold the PM sensor cable as we proposed in the pictures, to obtain a more compact hub!

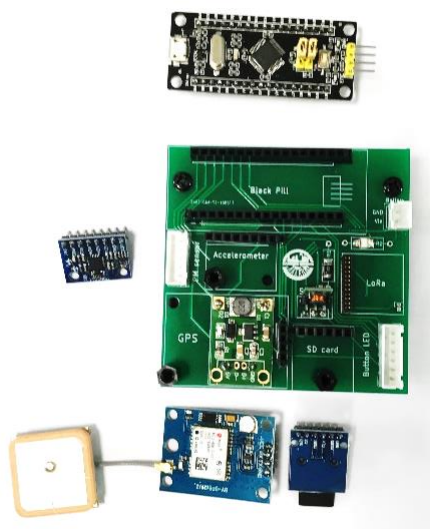
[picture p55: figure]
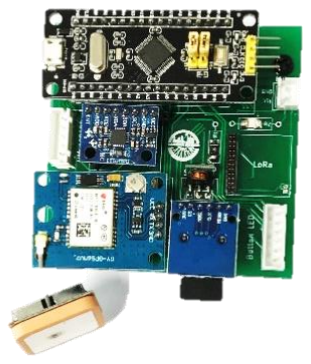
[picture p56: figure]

5. Finally, add the 2x 6 mm screws to fix the GPS and the accelerometer.

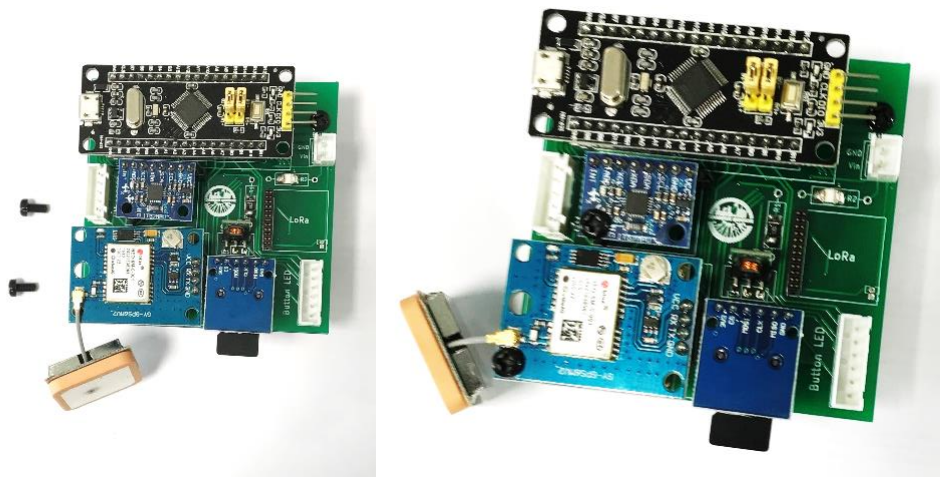
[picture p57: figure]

Once you have your electronics assembled, you can run the first tests to check if it works!

## Checking the sensor hub

You can now plug the battery in its connector. Make sure you are plugging the red cable in Vin and the black one in GND!

There are some LEDs you need to check:

Microcontroller:
It has 2 LEDs (either 2 red LEDs, either one blue and one red, depending on the version of the microcontroller). One is permanently on, so that is the first test required. If no lights are on, there is a problem with the connections and you should disconnect the battery and check that everything is correctly plugged. The second LED blinks every time data is read from the PM sensor and saved to the SD card. It takes about 30 s for the sensor hub to initialise, so you need to wait a bit to see if it’s working correctly. Once it starts blinking, it blinks every 3s. Sometimes it’s on for a very short time, sometimes it stays on longer. Don’t worry, it’s normal behaviour. The reason is that it waits for the PM sensor to send data and this time is variable!
Accelerometer:
It has a green LED that should be permanently on.

GPS:
It has a blue LED that blinks when there is connection to the satellites. To check that GPS is working correctly, you need to be outdoors. It takes about a minute for the GPS to lock to the satellites and then it starts blinking. If after a few minutes it still doesn’t blink, check the connection of the antenna, or move it around in case there are interferences. If it doesn’t improve, then try changing the module.
Step-up:
You also should be able to see a red light coming from below the GPS module. It’s the step-up regulator, and it should be permanently on.

Once you have checked all the lights, you can remove the SD card and see the data in your computer!

If you have any question about the mounting or functioning, don’t doubt to drop us an email at: info@cambikesensor.net.

## The case

We have designed a laser-cut case made of wood and with a transparent lid, so you can see what’s going on with the electronics! You can find the files in the casing folder of our GitHub repository. (https://github.com/sh969/CambikeSensor/tree/master/casing/Laser_cut_makespace) There is a specific entry about its mounting in the wiki.

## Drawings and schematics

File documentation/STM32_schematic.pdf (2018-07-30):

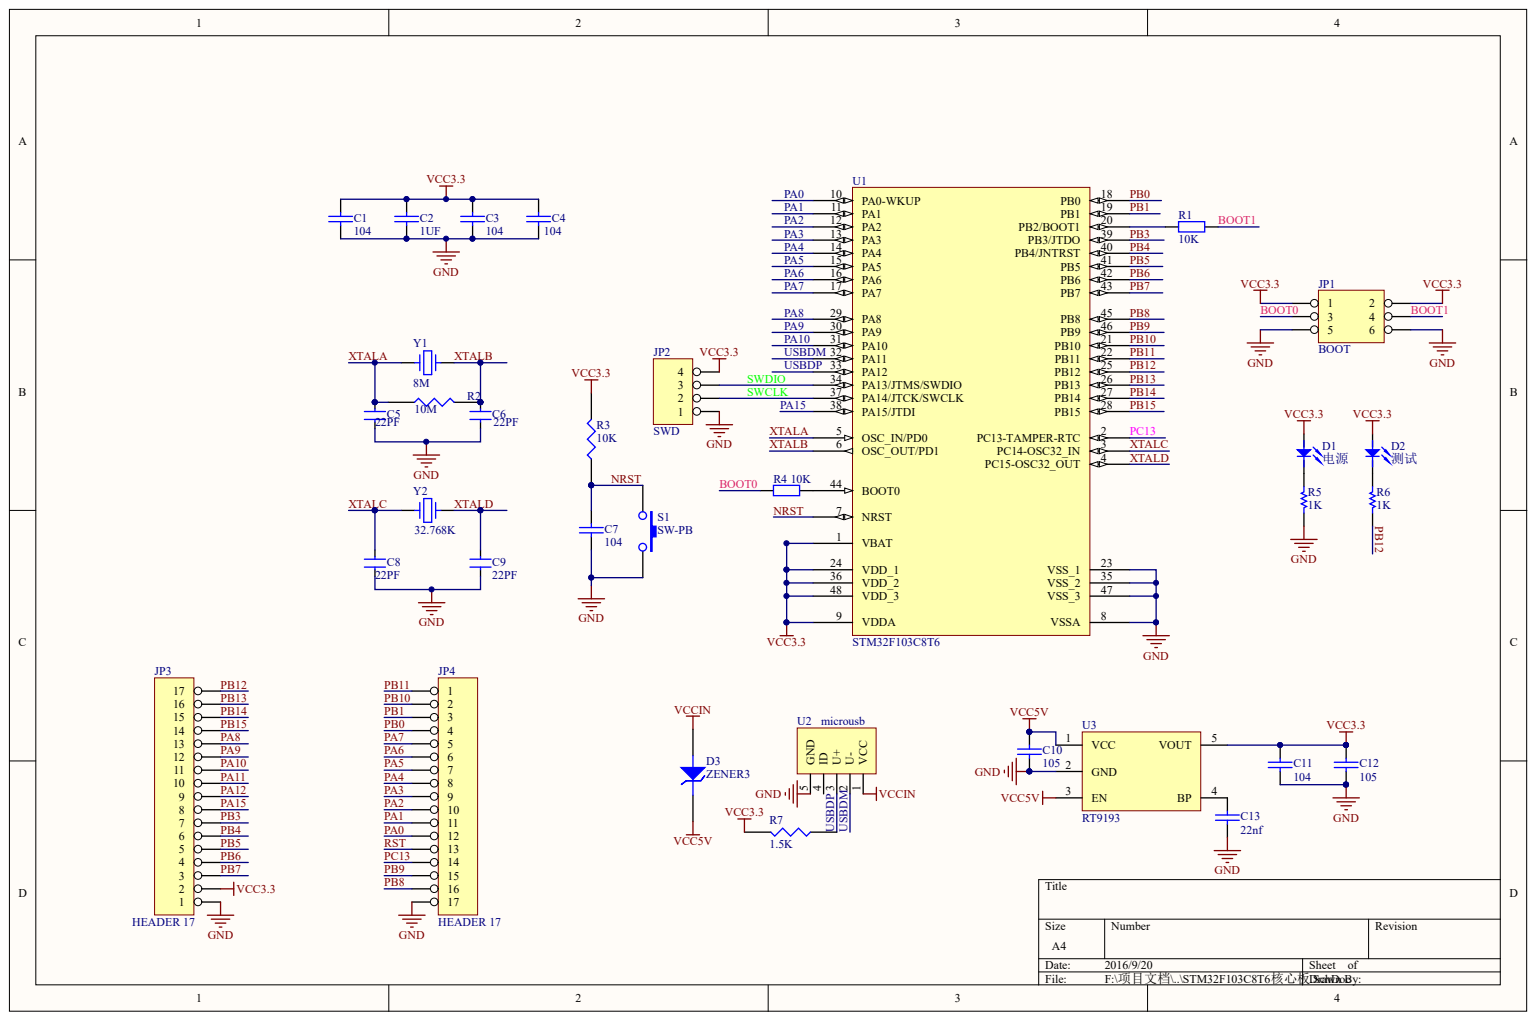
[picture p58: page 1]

VDD_1 24
VDD_2 36
VDD_3 48

CC 1 U- 2 U+ 3 ID 4 GND 5 U2 microusb

Comment | Description | Designator | Footprint | LibRef | Quantity
104 | [NoValue], [NoValue], [NoValue], [NoValue], Capacitor | C1, C3, C4, C7, C11 | 0603C | CAP | 5
1UF | | C2 | 0603C | CAP | 1
22PF | SMD-CAP | C5, C6, C8, C9 | 0603C | CAP-0.1UF | 4
105 | Capacitor | C10, C12 | 0603C | CAP | 2
22nf | Capacitor | C13 | 0603C | CAP | 1
电源 | | D1 | 0603D | LED | 1
测试 | | D2 | 0603D | LED | 1
ZENER3 | Zener Diode | D3 | 0805D | ZENER3 | 1
BOOT | | JP1 | HDR2X3 | HEADER 3X2 | 1
SWD | 4 Pin Header | JP2 | HDR1X4 | 4 HEADER | 1
HEADER 17 | | JP3, JP4 | | HEADER 17 | 2
Res2 | Resistor | R1, R4 | 0603B | Res2 | 2
10M | | R2 | 0603B | RES1 | 1
10K | | R3 | 0603B | RES1 | 1
1K | Resistor | R5, R6 | 0603B | Res1 | 2
1.5K | | R7 | 0603B | RES1 | 1
SW-PB | | S1 | 贴片按键 | SW-PB | 1
STM32F103C8T6 | STM32 ARM-based 32-bit MCU with 64 Kbytes Flash, 48-pin LQFP, Industrial Temperature | U1 | LQFP48_N | STM32F103C8T6 | 1
microusb | | U2 | MICRO-USB | microusb | 1
RT9193 | | U3 | SOT23-5 | RT9193 | 1
8M | 晶振 | Y1 | 49SMD | XT | 1
32.768K | 晶振 | Y2 | 晶振 32.768K | XT | 1

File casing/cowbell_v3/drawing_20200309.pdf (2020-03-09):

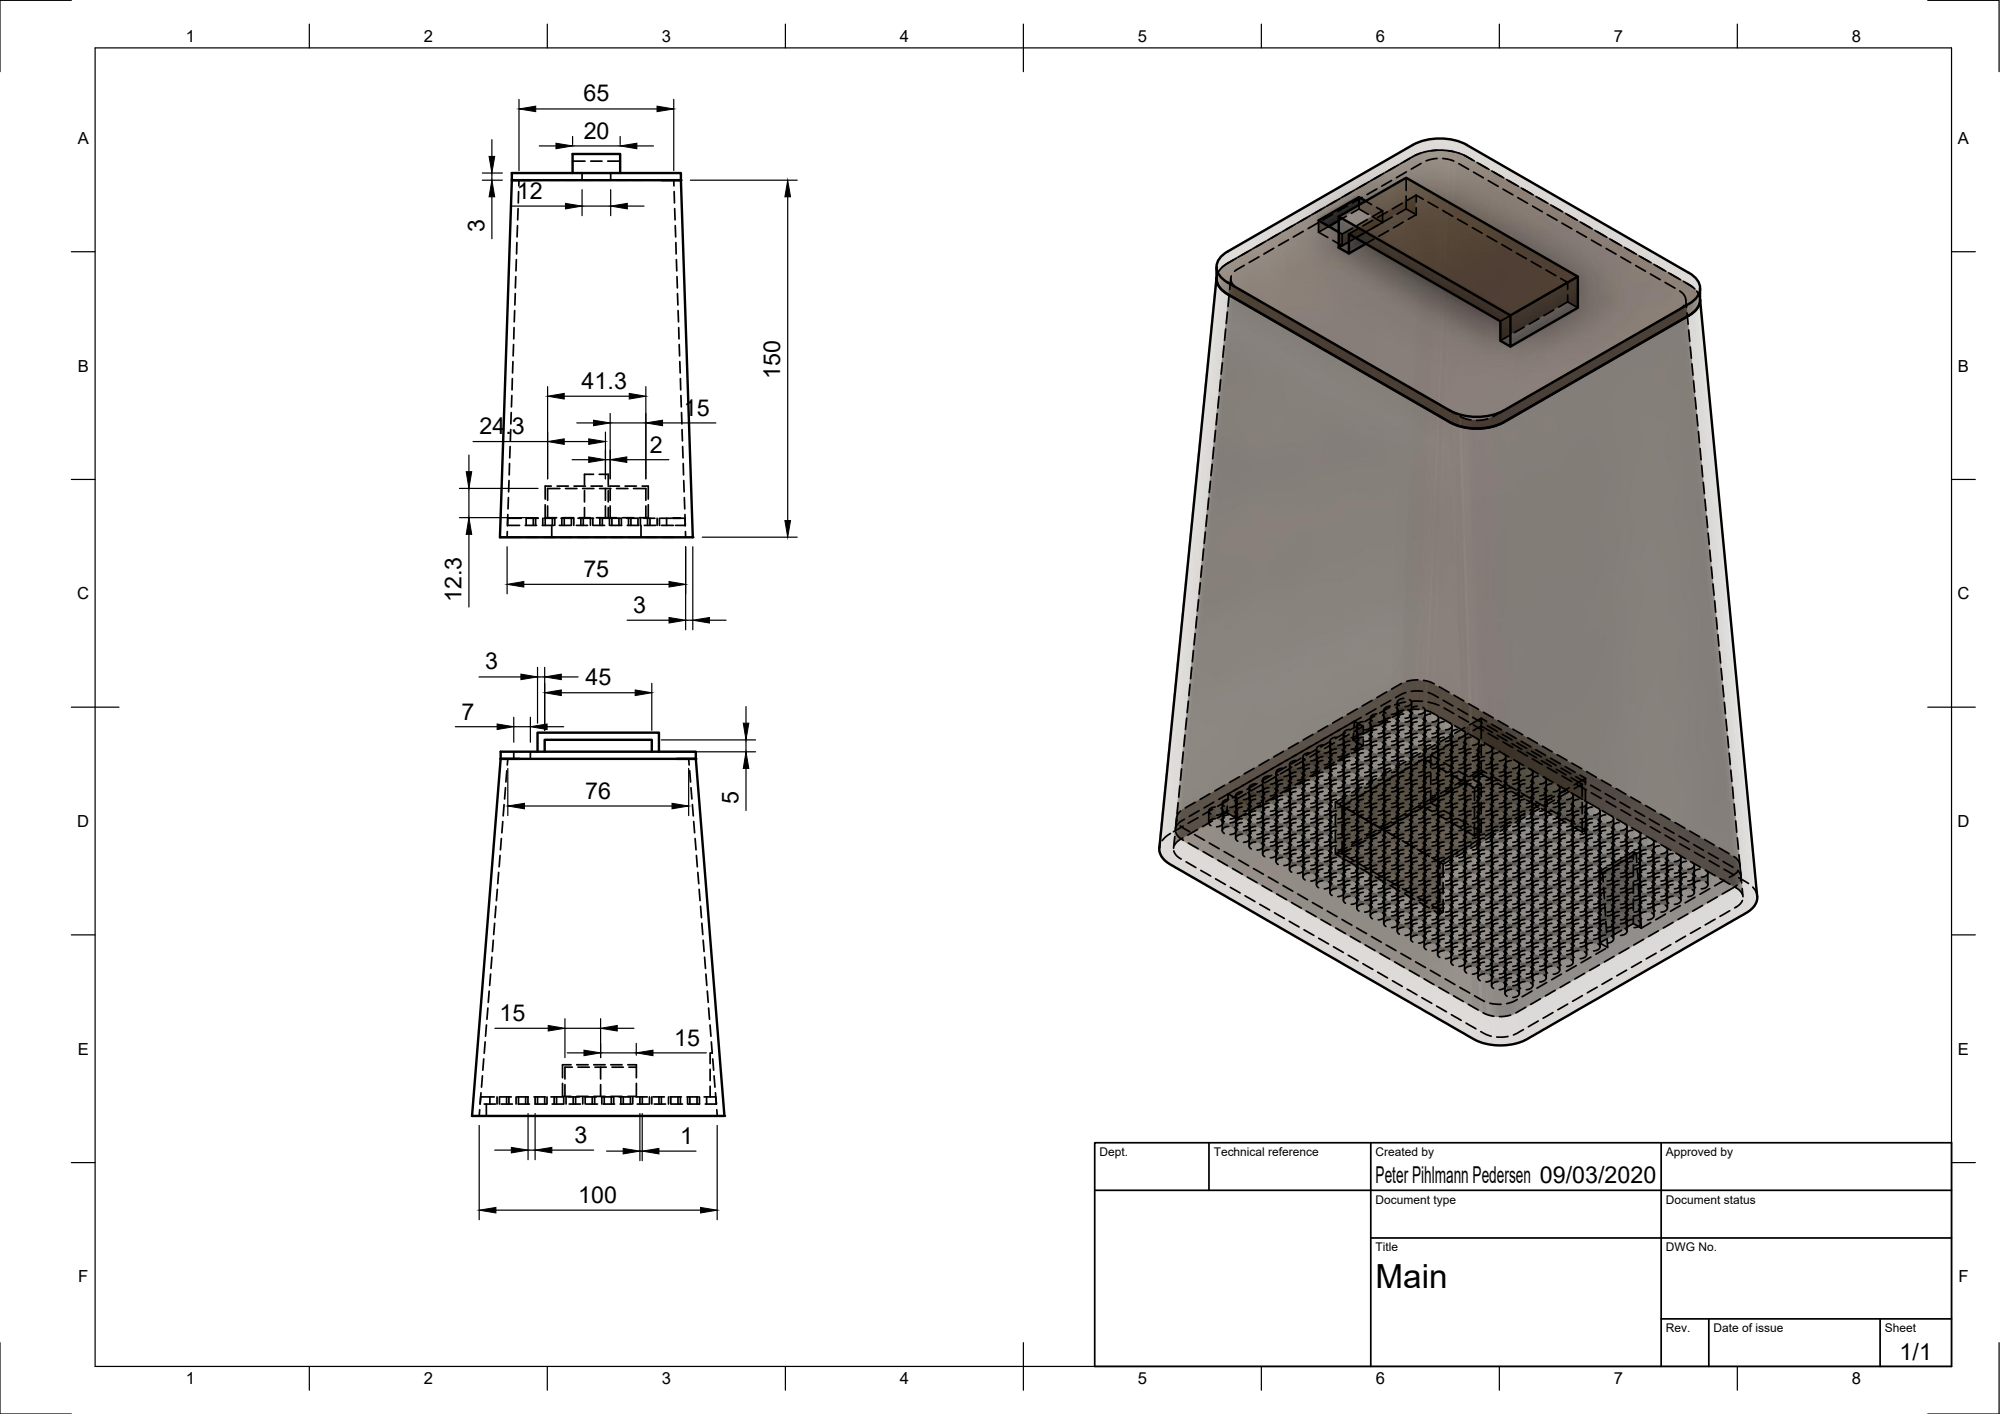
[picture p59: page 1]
Dept.; Technical reference; Created by; Approved by; Document type; Document status; Title; DWG No.; Rev.; Date of issue; Sheet

Peter Pihlmann Pedersen

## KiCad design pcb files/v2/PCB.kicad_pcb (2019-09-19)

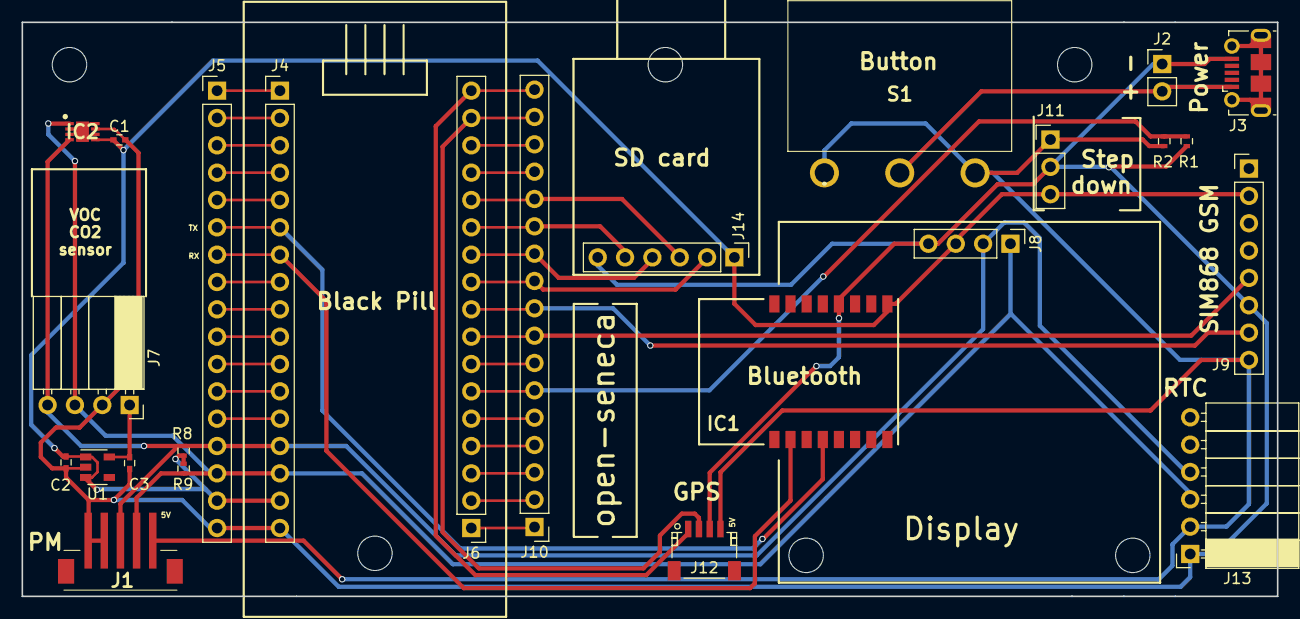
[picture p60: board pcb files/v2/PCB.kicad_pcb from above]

Board: 2 copper layers, 116.6 x 53.3 mm, 31 parts (0 on the bottom side), 37 nets.

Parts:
C1: 100 nF; C_0402
C2, C3: 1 uF; C_0402
IC1: HM-11; HM-11-MODULE
IC2: SHT31-DIS-B; SON50P250X250X90-9N-D
J1: Conn_01x05; B5B-ZR-SM4-TF
J2: Conn_01x02; Pin_Header_Straight_1x02_Pitch2.54mm
J3: USB_OTG; USB_Micro-B_Molex-105017-0001
J4, J5, J6, J10: Conn_01x17; Socket_Strip_Straight_1x17_Pitch2.54mm
J7: Conn_01x04; Socket_Strip_Angled_1x04_Pitch2.54mm
J8: Conn_01x04; Socket_Strip_Straight_1x04_Pitch2.54mm
J9: Conn_01x08; Socket_Strip_Straight_1x08_Pitch2.54mm
J11: Conn_01x03; Socket_Strip_Straight_1x03_Pitch2.54mm
J12: Conn_01x04; JST_SH_SM04B-SRSS-TB_04x1.00mm_Angled
J13: Conn_01x06; Socket_Strip_Angled_1x06_Pitch2.54mm
J14: Conn_01x06; Socket_Strip_Straight_1x06_Pitch2.54mm
MK1, MK2, MK3, MK4, MK5, MK6: Mounting_Hole; MountingHole_3.2mm_M3
R1, R2, R8, R9: 4.7k; R_0402
S1: CWSA11AAN1H
U1: TLV70218_SOT23-5; SOT-23-5

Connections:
+3V3: C1.1, C2.1, IC1.9, IC2.5, J4.16, J5.16, J8.3, J9.2, J11.3, J14.1, R8.2, R9.2, U1.1, U1.3
+5V: J1.1, J9.8, J11.1, J12.4, J13.2, R2.1, S1.1, S1.3
/BT_RX: IC1.4, J4.6, J5.6
/BT_TX: IC1.2, J4.7, J5.7
/Bat: J6.6, J10.6, R1.1, R2.2
/Blue: J6.7, J10.7
/CStoSD: J6.10, J10.10, J14.2
/GPS_RX: J6.16, J10.16, J12.2
/GPS_TX: J6.17, J10.17, J12.1
/GSM_RX: J6.8, J9.5, J10.8
/GSM_TX: J6.9, J9.7, J10.9
/Green: J6.14, J10.14
/MISOtoSD: J6.12, J10.12, J14.5
/MOSItoSD: J6.13, J10.13, J14.3
/Red: J6.15, J10.15
/SCKtoSD: J6.11, J10.11, J14.4
/SCL: IC2.4, J1.3, J4.14, J5.14, J7.4, J8.2, J13.4, R8.1
/SDA: IC2.1, J1.2, J4.15, J5.15, J7.3, J8.1, J13.3, R9.1
GND: C1.2, C2.2, C3.2, IC1.12, IC2.2, IC2.7, IC2.8, IC2.9, J1.4, J1.5, J2.1, J3.5, J4.17, J5.17, J7.2, J8.4, J9.6, J11.2, J12.3, J13.1, J14.6, R1.2, U1.2
unnamed: C3.1, J7.1, U1.5
unnamed: J2.2, J3.1, S1.2
unnamed: J4.1, J5.1
unnamed: J4.2, J5.2
unnamed: J4.3, J5.3
unnamed: J4.4, J5.4
unnamed: J4.5, J5.5
unnamed: J4.8, J5.8
unnamed: J4.9, J5.9
unnamed: J4.10, J5.10
unnamed: J4.11, J5.11
unnamed: J4.12, J5.12
unnamed: J4.13, J5.13
unnamed: J6.1, J10.1
unnamed: J6.2, J10.2
unnamed: J6.3, J10.3
unnamed: J6.4, J10.4
unnamed: J6.5, J10.5

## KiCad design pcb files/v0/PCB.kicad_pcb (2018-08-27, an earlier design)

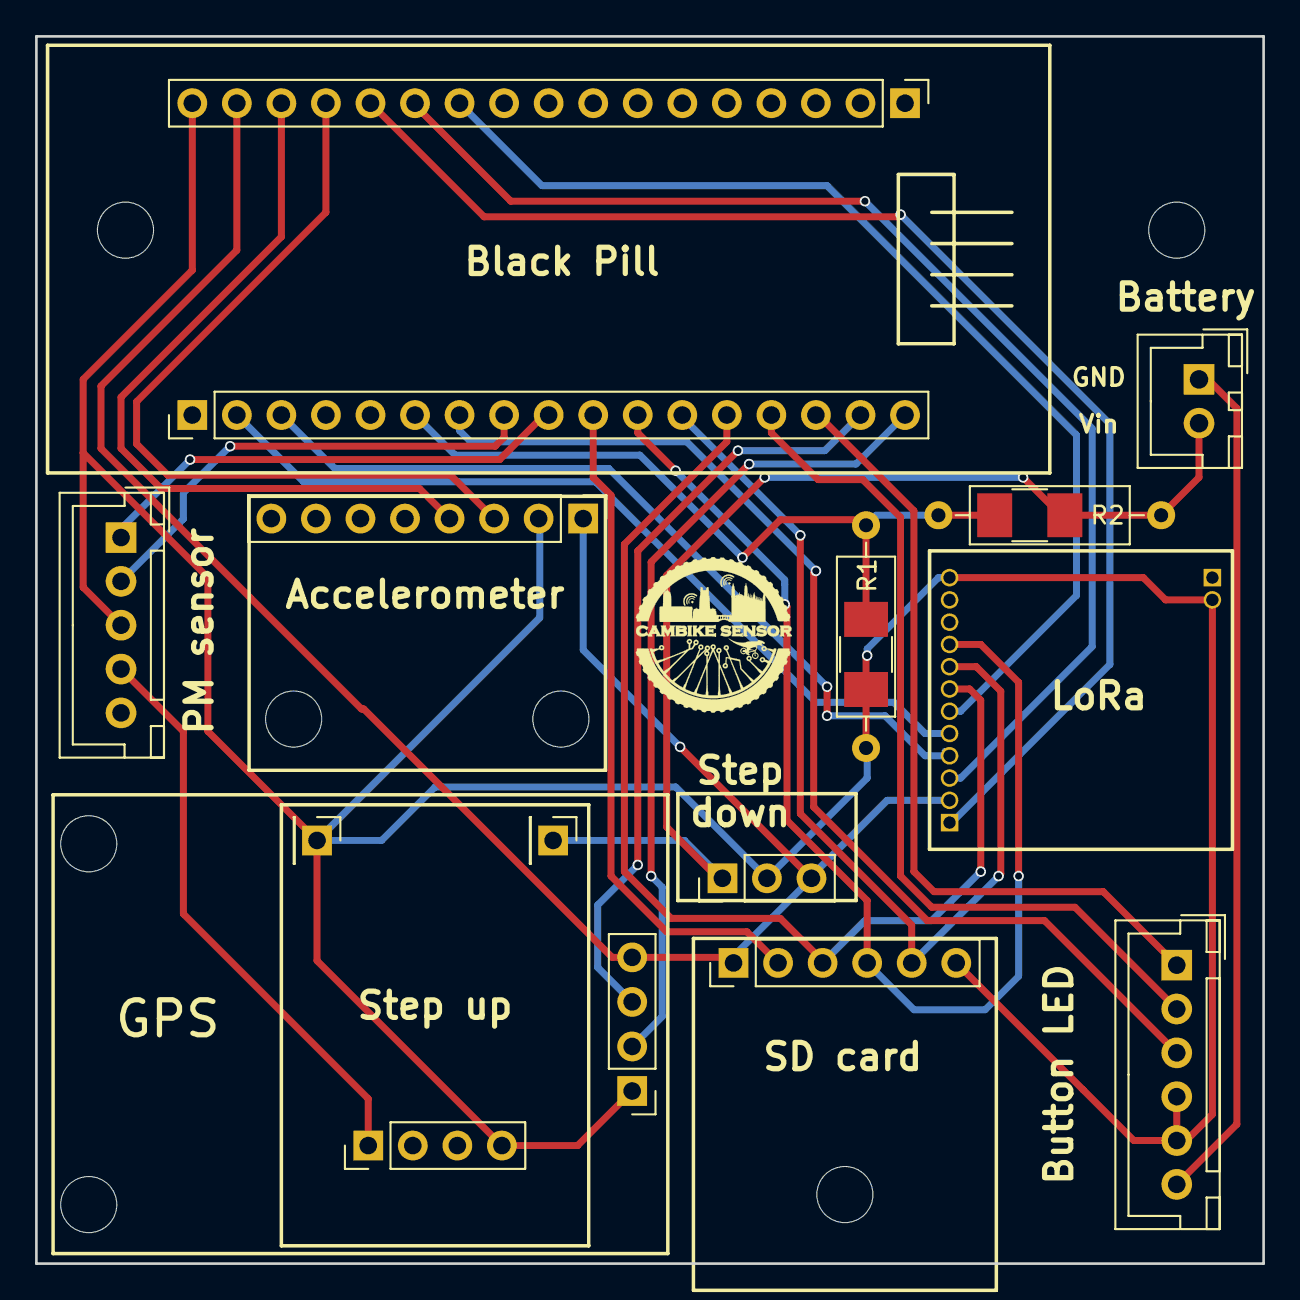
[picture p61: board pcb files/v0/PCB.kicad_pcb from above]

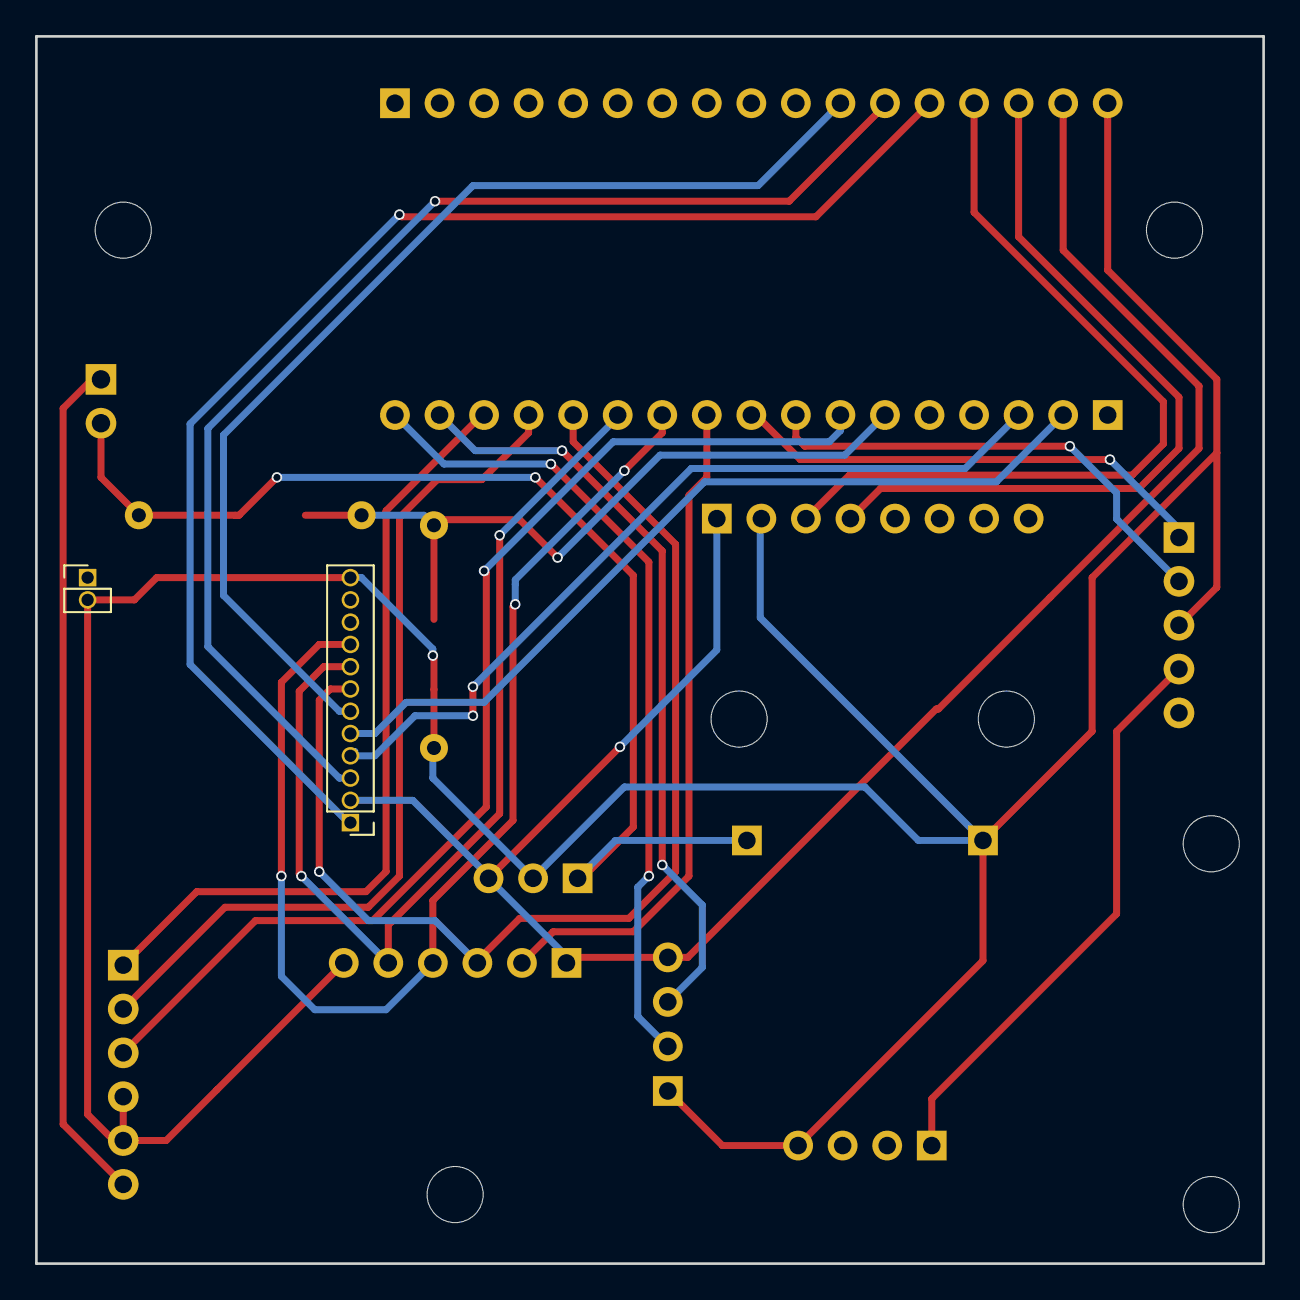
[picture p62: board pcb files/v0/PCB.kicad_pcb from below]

Board: 2 copper layers, 70.0 x 70.0 mm, 25 parts (2 on the bottom side), 24 nets.

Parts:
J1: Conn_01x08; Socket_Strip_Straight_1x08_Pitch2.54mm
J2: Conn_01x02; Socket_Strip_Straight_1x02_Pitch1.27mm
J3: Conn_01x12; Socket_Strip_Straight_1x12_Pitch1.27mm
J4: Conn_01x02; JST_XH_B02B-XH-A_02x2.50mm_Straight
J5, J10: Conn_01x17; Socket_Strip_Straight_1x17_Pitch2.54mm
J6, J7: Conn_01x01; Socket_Strip_Straight_1x01_Pitch2.54mm
J8: Conn_01x06; JST_XH_B06B-XH-A_06x2.50mm_Straight
J9, J12: Conn_01x04; Socket_Strip_Straight_1x04_Pitch2.54mm
J11: Conn_01x03; Socket_Strip_Straight_1x03_Pitch2.54mm
J13: Conn_01x05; JST_XH_B05B-XH-A_05x2.50mm_Straight
J14: Conn_01x06; Socket_Strip_Straight_1x06_Pitch2.54mm
MK1, MK2, MK3, MK4, MK5, MK6, MK7: Mounting_Hole; MountingHole_3.2mm_M3
R1, R2: 22k; R_1210_HandSoldering
R3, R4: 22k; R_Axial_DIN0309_L9.0mm_D3.2mm_P12.70mm_Horizontal

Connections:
+3V3: J1.1, J3.2, J5.16, J11.3, J12.4, J14.1
+5V: J9.1, J13.4
/Bat: J10.6, R1.1, R2.2, R3.1, R4.2
/Blue: J8.3, J10.7
/CS: J3.6, J5.11
/CStoSD: J10.10, J14.2
/DI0: J3.3, J5.12
/DI01: J3.4, J10.3
/DI02: J3.5, J10.2
/GPS_RX: J10.16, J12.3
/GPS_TX: J10.17, J12.2
/Green: J8.2, J10.14
/MISOtoSD: J3.8, J10.12, J14.5
/MOSItoSD: J3.7, J10.13, J14.3
/NO: J4.1, J8.6
/RESET: J3.1, J5.13
/RXtoSDS: J10.8, J13.2
/Red: J8.1, J10.15
/SCKtoSD: J3.9, J10.11, J14.4
/SCL: J1.3, J5.14
/SDA: J1.4, J5.15
/TXtoSDS: J10.9, J13.1
/Vin: J4.2, J6.1, J11.1, R2.1, R4.1
GND: J1.2, J2.2, J3.12, J5.17, J7.1, J8.4, J8.5, J9.4, J11.2, J12.1, J13.3, J14.6, R1.2, R3.2

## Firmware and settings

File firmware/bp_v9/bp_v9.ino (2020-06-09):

#include <SPI.h>
#include <SD.h>
#include <Wire.h> // BUFFER_LENGTH 32 in WireBase.h and Wire_slave.cpp has been increased to 64 to read full SPS30 buffer (download from our Github)
#include "Adafruit_SHT31.h"
#include <Adafruit_SSD1306.h>

#define LED PB12
#define CSPIN PA4
#define VINPIN PA0
#define RED PB1 // former LED1
#define GREEN PB0
#define BLUE PA1
#define SDA PB7
#define SCL PB6

#define SHT31_addr 0x44
#define SPS30_addr 0x69
#define SSD1306_addr 0x3C
#define SGP30_addr 0x58
#define SGP30_FEATURESET 0x0020    ///< The required set for this library
#define SGP30_CRC8_POLYNOMIAL 0x31 ///< Seed for SGP30's CRC polynomial
#define SGP30_CRC8_INIT 0xFF       ///< Init value for CRC
#define SGP30_WORD_LEN 2           ///< 2 bytes per word

// tinyGSM here
#define TINY_GSM_MODEM_SIM808
// set GSM PIN, if any
#define GSM_PIN ""
// Your GPRS credentials, if any
const char apn[]  = "TM";
const char gprsUser[] = "";
const char gprsPass[] = "";
// #define TINY_GSM_DEBUG Serial
#include <TinyGsmClient.h>
TinyGsm modem(Serial1);
TinyGsmClient client(modem);
boolean sim868_connected = false;

int year, month, day, hour, minute, second, alt=0, vsat=0, usat=0;
float speed=0;
String lat="0", lon="0";

// OLED here
#define SCREEN_WIDTH 128 // OLED display width, in pixels
#define SCREEN_HEIGHT 64 // OLED display height, in pixels
#define ROTATION 1 // OLED display rotation // 0: landscape, 1: portrait, 3: portrait2

// Declaration for an SSD1306 display connected to I2C (SDA, SCL pins)
#define OLED_RESET     4 // Reset pin # (or -1 if sharing Arduino reset pin)
Adafruit_SSD1306 display(SCREEN_WIDTH, SCREEN_HEIGHT, &Wire, OLED_RESET);
bool display_connected = true; // does not seem to work yet, implement i2c address check at bootup

String code_version = "BlackPill_v9";
String header = "Counter,Latitude,Longitude,gpsUpdated,Speed,Altitude,Satellites,Date,Time,Millis,PM1.0,PM2.5,PM4.0,PM10,Temperature,Humidity,NC0.5,NC1.0,NC2.5,NC4.0,NC10,TypicalParticleSize,TVOC,eCO2,BatteryVIN";


File myFile;
String filename;
uint32_t mtime;

// Humidity and temperature sensor SHT31
Adafruit_SHT31 sht31 = Adafruit_SHT31();

// VOC sensor SGP30
uint16_t sgp30_sn[3];
uint16_t TVOC = 0; // Total Volatile Organic Compounds in ppb
uint16_t eCO2 = 0; // Equivalent CO2 in ppm
bool sgp_connected = true;

// PM sensor SPS30
float mc_1p0, mc_2p5, mc_4p0, mc_10p0, nc_0p5, nc_1p0, nc_2p5, nc_4p0, nc_10p0, typical_particle_size = -1;
byte w1, w2,w3;
byte ND[60];
long tmp;
float measure[10];
String sps30_sn;

//GSM module
String imei = "", cnum = "", payload = "";

float vin = 0, temperature = 20.0f, humidity = 50.0f;
int counter=0, gpsUpdated = 0;
uint32_t abs_hum = 0.0f;

void setup() {
    // set up LEDs and turn on
    pinMode(LED, OUTPUT);
    digitalWrite(LED, HIGH);
    
    // Open serial communications and wait for port to open:
    Serial.begin(9600); // Bluetooth
    Serial1.begin(TinyGsmAutoBaud(Serial1)); // SIM868
//    Serial2.begin(9600); // ublox GPS, not needed for v9 upwards
    delay(50); 

    // check if battery level is OK and output it to debug output
    /*if (!batteryOk()) {
        Serial.print(F("Battery voltage is low: "));
    } else {
        Serial.print(F("Battery voltage is ok: "));
    }
    Serial.println(vin);*/
 
    // initialise SD card
    if (!SD.begin(CSPIN)) Serial.println(F("SD card not available."));
    else Serial.println(F("SD card found."));
   
  // Testing humidity sensor
  if (! sht31.begin(0x44)) {   // Set to 0x45 for alternate i2c addr
    Serial.println(F("SHT31 sensor not available."));
//    while (1) delay(1);
  }
  else Serial.println(F("SHT31 sensor initiated."));

  // Testing VOC sensor
  if (!SGP30_init(SGP30_addr)) {
    Serial.println(F("SGP30 sensor not available."));
    sgp_connected = false;
  }
  else {
    Serial.println(F("SGP30 sensor initiated."));  
    Serial.print("SGP30 serial #: ");
    Serial.print(sgp30_sn[0], HEX);
    Serial.print(sgp30_sn[1], HEX);
    Serial.println(sgp30_sn[2], HEX);
  }

    // OLED display intialisation
    if(!display.begin(SSD1306_SWITCHCAPVCC, SSD1306_addr, false, false)) { // SSD1306_SWITCHCAPVCC = generate display voltage from 3.3V internally
      Serial.println(F("SSD1306 allocation failed")); // doesn't work, method never returns false
      display_connected = false;
    }  
    if (display_connected) {
      Serial.println(F("SSD1306 display initiated."));
      // Show initial display buffer contents on the screen --
      // the library initializes this with an Adafruit splash screen.
  //    display.display();
  //    delay(2000); // Pause for 2 seconds  
      // Clear the buffer
      display.clearDisplay();  
      display.setTextColor(WHITE);
      display.setTextSize(2); // Draw 2X-scale text
      display.setCursor(0, 0);
      display.println(F("openseneca"));
      display.setTextSize(1);
      display.println(F("air quality sensing"));
      display.println(F("powered by citizen"));
      display.println(F("science"));
      display.println(); display.println();
      display.println(code_version);
      display.display();      // Show initial text
      Serial.println(F("SSD1306 display updated."));
    }

   //Testing PM sensor
    SPS30_start_measurement();
    SPS30_cleaning();
    sps30_sn = SPS30_getSerialNumber();

// old
//////////////////////////////////////////////////////////////////////////////////////////////////////////////////////////////////////////////////////
//    // Initialise GSM
//    //while (Serial1.available() > 0){ 
//    if (!initSIM()) Serial.println("GSM module not available.");
//    else {    
//      Serial.print(F("GSM module found, IMEI: "));
//      Serial.println(imei);
//      if (cnum != "") {
//        Serial.print(F("SIM card number: "));
//        Serial.println(cnum);
//      }
//      else Serial.println(F("No SIM card."));
//    }
//    
//    delay(50);
//    // print whether GPS data communication is enabled or not
//    if (Serial2.available() > 0) {
//        Serial.println(F("GPS module found."));
//    } else {
//        gps_connected = false;
//        Serial.println(F("GPS module not available."));
//    }
//////////////////////////////////////////////////////////////////////////////////////////////////////////////////////////////////////////////////////
    // Restart takes quite some time
    // To skip it, call init() instead of restart()
    Serial.println("Initializing modem...");
    if (modem.restart()) Serial.println("SIM card found");
    else Serial.println("No SIM card found");
    if (modem.enableGPS()) {
      sim868_connected = true;
      Serial.println("GPS activated");
    }
    else Serial.println("No GPS module found");

 
    // open the file. Note that only one file can be open at a time,so you have to close this one before opening another.
    filename = getNextName();
    delay(50);
    Serial.print(F("Filename: ")); Serial.print(filename); Serial.println(F(".csv"));
    delay(50);
    digitalWrite(LED, LOW);
    myFile = SD.open(filename + ".csv", FILE_WRITE);

    // if the file opened okay, write to it:
    if (myFile) {
        myFile.print(code_version); myFile.print(", IMEI: "); myFile.print(imei); myFile.print(", SIM card number: "); myFile.print(cnum); myFile.print(", SPS30 SN: "); myFile.print(sps30_sn); myFile.print(", SGP30 SN: "); myFile.print(sgp30_sn[0], HEX); myFile.print(sgp30_sn[1], HEX); myFile.print(sgp30_sn[2], HEX); myFile.println();
        myFile.println(header);
        
        // close the file:
        myFile.close();
    }

    // print the data to debug output as well
    Serial.println(header);
            
    digitalWrite(LED, HIGH);
    mtime = millis();
}

void loop() {    
    // check that 3 seconds have passed, since this is our data collection timeframe
    if (millis() - mtime > 1000) {
      routine();
    }
} //end loop

// FUNCTIONS

void routine() {
    // turn on LED for user feedback
    digitalWrite(LED, LOW);

    // read in battery level
    batteryOk();

    // Read PM sensor SPS30
    SPS30_reading();

    // Read temperature and humidity 
    temperature = sht31.readTemperature();
    humidity = sht31.readHumidity();
    
    // run humidity correction on VOC sensor
//    abs_hum = getAbsoluteHumidity(temperature, humidity);//2167 * humidity * 6112 / (273150 + temperature) * exp(1762 * temperature / (24312 + 10*temperature)); // [mg/m^3]
//    if (!SGP30_setHumidity(abs_hum)) Serial.println(F("SGP humidity correction failed."));
//    else Serial.println(F("SGP humidity corrected."));
   
    if (sgp_connected) SGP30_measure();
//    Serial.print("TVOC "); Serial.print(TVOC); Serial.print(" ppb\t");
//    Serial.print("eCO2 "); Serial.print(eCO2); Serial.println(" ppm");

    // optional: set baseline recorded or saved in non-volatile memory
//    if (counter%6 == 0) {
//      uint16_t TVOC_base, eCO2_base;
//      if (!SGP30_getIAQBaseline(&eCO2_base, &TVOC_base)) {
//        Serial.println("Failed to get baseline readings");
//        return;
//      }
//      Serial.print("****Baseline values: eCO2: 0x"); Serial.print(eCO2_base, HEX);
//      Serial.print(" & TVOC: 0x"); Serial.println(TVOC_base, HEX);
//    }

    lat="0", lon="0", speed=0, alt=0, vsat=0, usat=0; // viewed/used satellites
    if (sim868_connected) {
      Serial.println(modem.getGPSraw());
      modem.getGPSTime(&year, &month, &day, &hour, &minute, &second);
      if (modem.getGPS(&lat, &lon, &speed, &alt, &vsat, &usat)) gpsUpdated = 1;
      else gpsUpdated = 0;
      if (lat == "") lat = lon = "0";
    }
    
    payload = String(counter) + "," +
              lat + "," + 
              lon + "," + 
              String(gpsUpdated)+ "," + 
              String(speed) + "," + 
              String(alt) + "," + 
              String(vsat)+ "," + 
              String(formatDate())+ "," +
              String(formatTime())+ "," +
              String(mtime)+ "," + 
              String(mc_1p0)+ "," + 
              String(mc_2p5)+ "," + 
              String(mc_4p0)+ "," + 
              String(mc_10p0)+ "," + 
              String(temperature)+ "," + 
              String(humidity)+ "," + 
              String(nc_0p5)+ "," + 
              String(nc_1p0)+ "," + 
              String(nc_2p5)+ "," + 
              String(nc_4p0)+ "," +
              String(nc_10p0)+ "," + 
              String(typical_particle_size)+ "," + 
              String(TVOC)+ "," + 
              String(eCO2)+ "," + 
              String(vin);
//    if (imei != "") uploadSIM(payload); //////////////////////////////////////////////////////////////////////////////////////////////////////////////////////////////////////////////////////
    
    // open file to write sensor data
    myFile = SD.open(String(filename) + ".csv", FILE_WRITE);
    
    // if the file opened successfully, write the sensor data to it
    if (myFile) {
      myFile.println(payload);
      myFile.close();
      // turn off LED for user feedback
      digitalWrite(LED, HIGH);
    }

    // print data to serial output for debugging purposes
    delay(100);
    Serial.println(payload);

    // update data on OLED screen
    if (display_connected) {
      updateDisplay();
    }
    
    // set current time
    mtime = millis();
  
    counter++;
}

void updateDisplay() {  
    // show on OLED
    // row 0-15 are yellow, 16-63 blue
    display.clearDisplay();   
    #if ROTATION == 1
      display.setRotation(1);
      display.setCursor(0, 0); display.setTextSize(1); display.println("PM2");
      display.setCursor(16, 0); display.setTextSize(2); display.print(String(mc_2p5).substring(0,4));
      display.setCursor(16, 16); display.setTextSize(1); display.println("ug/m3");
      
      display.setCursor(0, 28); display.setTextSize(1); display.print("VOC");
      display.setCursor(16, 28); display.setTextSize(2); display.print(String(TVOC).substring(0,4));
      display.setCursor(16, 44); display.setTextSize(1); display.println("ppb");
      
      display.setCursor(0, 60); display.setTextSize(1); display.print("CO2");
      display.setCursor(16, 60); display.setTextSize(2); display.print(String(eCO2).substring(0,4));
      display.setCursor(16, 76); display.setTextSize(1); display.println("ppm");
      
      display.setCursor(0, 88); display.setTextSize(1); display.print("T");
      display.setCursor(16, 88); display.setTextSize(2); display.print(String(round(temperature))+" C");
      display.setCursor(0, 106); display.setTextSize(1); display.print("RH");
      display.setCursor(16, 106); display.setTextSize(2); display.print(String(round(humidity))+" %");

      display.setCursor(0, 120); display.setTextSize(1); 
      for (int i=0; i<vsat; i++) display.print(".");
    #elif ROTATION == 3
      display.setRotation(3);
      display.setCursor(48, 0); display.setTextSize(1); display.println("PM");
      display.setCursor(0, 0); display.setTextSize(2); display.print(String(mc_2p5).substring(0,4));
      display.setCursor(0, 16); display.setTextSize(1); display.println("ug/m3");
      
      display.setCursor(48, 28); display.setTextSize(1); display.print("VO");
      display.setCursor(0, 28); display.setTextSize(2); display.print(String(TVOC).substring(0,4));
      display.setCursor(0, 44); display.setTextSize(1); display.println("ppb");
      
      display.setCursor(48, 60); display.setTextSize(1); display.print("CO");
      display.setCursor(0, 60); display.setTextSize(2); display.print(String(eCO2).substring(0,4));
      display.setCursor(0, 76); display.setTextSize(1); display.println("ppm");
      
      display.setCursor(48, 88); display.setTextSize(1); display.print("T");
      display.setCursor(0, 88); display.setTextSize(2); display.print(String(round(temperature))+" C");
      display.setCursor(48, 106); display.setTextSize(1); display.print("RH");
      display.setCursor(0, 106); display.setTextSize(2); display.print(String(round(humidity))+" %");

      display.setCursor(0, 120); display.setTextSize(1); 
      for (int i=0; i<vsat; i++) display.print(".");
    #else // rotation 0
      display.setTextSize(1); 
//      display.setTextColor(WHITE);
      display.setCursor(0, 0);
      display.print(String(hour)+F(":")+String(minute));
      display.setCursor(52, 0);
      display.print(String(round(humidity))+F(" %"));
      display.setCursor(100, 0);
      display.println(String(round(temperature))+F(" C"));
      display.setCursor(0, 16); //display.println(); 
      display.setTextSize(3); display.print(String(mc_2p5).substring(0,5));
      display.setTextSize(1); display.println("ug/m3");    
      display.setCursor(0, 42);  
      display.setTextSize(3); display.print(String(TVOC).substring(0,5));
      display.setTextSize(1); display.println("ppb"); 
    #endif
    display.display();
}

// format date in the following format:
// YYYYMMDD
String formatDate() {
    String out = "";
    out += String(year);
    out += formatInt(month, 2);
    out += formatInt(day, 2);
    return out;
}

// format time in the following format:
// HHMMSS
String formatTime() {
    String out = "";
    out += formatInt(hour, 2);
    out += formatInt(minute, 2);
    out += formatInt(second, 2);
    return out;
}

// format an integer as a string with the required number of digits of precision
// if the number of digits in the integer is larger than precision, return the largest number
// possible using that precision ie. precision number of 9s
String formatInt(int num, int precision) {
  // find the maximum
  int maximum = 1;
  for (int i = 0; i < precision; i++) {
    maximum *= 10;
  }
  maximum--;

  // if the number is too big, return the maximum number that can be represented using precision digits
  if (num > maximum) {
    return String(maximum);
  }

  // otherwise convert the integer and prepend 0s until full
  String out = String(num); // fill up with leading zeroes if necessary
  String zero = "";
  for (int i = 0; i < (precision - out.length()); i++) {
    zero += "0";
  }
  
  return (zero + out);
}

// check filenames on SD card and increment by one
String getNextName() {
  File root = SD.open("/");
  String output;
  if (sps30_sn == "") output = "000";
  else output = sps30_sn.substring(0, 3); // filenames longer than 6 digits are not being read so we only take 3 digits of the serial number
  int out = 100;
  while (true) {
    // check file
    File entry = root.openNextFile();

    // if opening the file doesn't return a correct file, we are done
    if (!entry) {
      break;
    }

    // check if the filename is in the correct range. If it is, increment the counter
    String temp = entry.name();
    temp = temp.substring(3 ,6);
    int num = temp.toInt();
    if (num < 999 && num >= out) {
      out = num + 1;
    }

    // close the file
    entry.close();
  }
  output = output+String(out);
  return output;
}


// checks if the battery voltage is OK and returns whether it is or not
boolean batteryOk() { // analog input can measure between 0 and supply voltage (3.3V)
    vin = 2 * 3.3 * analogRead(VINPIN) / 4095.0; // calculation based on 50:50 voltage divider to measure battery voltage between 0 and 6.6V
    if (vin < 3.5) {
        digitalWrite(RED, HIGH);
        return false;
    }
    else digitalWrite(RED, LOW);
    return true;
}

//boolean initSIM() {
//  long sim_start = millis();
//  bool module_present = 0;
//  
//  while ( millis() - sim_start < 5000 && module_present == 0) {
//      module_present = sendATcommand("AT+CFUN=1", "OK", 500);
//  }
//  
//  if (module_present == 0) return false; 
//  sendATcommand("AT+COPS=2", "OK", 2000);
//  sendATcommand("AT+COPS=0", "OK", 2000);
//  
//  while ( millis() - sim_start < 20000 && sim_connected == 0) {
//      if ( (sendATcommand("AT+CREG?", "+CREG: 1,1", 500) == 1 || sendATcommand("AT+CREG?", "+CREG: 1,5", 500) == 1 ||
//           sendATcommand("AT+CREG?", "+CREG: 0,1", 500) == 1 || sendATcommand("AT+CREG?", "+CREG: 0,5", 500)) == 1 ){
//            sim_connected = 1;
//          } else {
//            sim_connected = 0;
//          }
////      Serial.println(millis() - sim_start);
////      Serial.println(sim_connected);
//  }
//  sendATcommand("AT+CGATT?", "+CGATT: 1", 1000);
//
//  delay(100);
//  imei = runCommand("AT+CGSN").substring(0,15);
//  delay(100);
//  cnum = runCommand("AT+CNUM").substring(13,27);
//  
//  sendATcommand("AT+CSQ", "OK", 1000);
//  sendATcommand("AT+SAPBR=3,1,\"Contype\",\"GPRS\"", "OK", 5000);
//  sendATcommand("AT+SAPBR=3,1,\"APN\",\"TM\"", "OK", 5000);
//  sendATcommand("AT+SAPBR=1,1", "OK", 1000);
//  sendATcommand("AT+SAPBR=2,1", "OK", 1000);
//  sendATcommand("AT+HTTPINIT", "OK", 1000); 
//  return true;
//}
//
//void uploadSIM(String payload) {
//  runCommand("AT+HTTPPARA=\"URL\",\"http://app.open-seneca.org/php/gsmUpload.php?imei=" + imei + "&simnumber=" + cnum + "&payload=" + payload + "\"");
//  if ( runCommand("AT+HTTPACTION=0") == "ERROR" && sim_connected == 1){
//    initSIM();
//  }
//  runCommand("AT+HTTPREAD");
//}
//  
//String runCommand(String cmd) {
////  Serial.println(cmd);
//  Serial1.println(cmd);
//  delay(1000);
//  String resp = "";
//  
//  while(Serial1.available()) {
//    resp += (char)Serial1.read();
//  }
//
//  resp.replace("\r","");
//  resp.replace("\n","");
//
//  String filteredResp = "";
//  int i;
//  for(i = cmd.length(); i < resp.length(); i++) {
//      filteredResp += resp[i];
//  }
//
////  Serial.println("filtered: " + filteredResp);
//  return filteredResp;
//}
//
//int8_t sendATcommand(char* ATcommand, char* expected_answer, unsigned int timeout) {
//    uint8_t x=0,  answer=0;
//    char response[100];
//    unsigned long previous;
//
//    memset(response, '\0', 100);    // Initialice the string    
//    delay(100);
//    
//    while( Serial1.available() > 0) Serial1.read();    // Clean the input buffer
//    if (ATcommand[0] != '\0') {
//        Serial1.println(ATcommand);    // Send the AT command 
//    }
//    
//    x = 0;
//    previous = millis();
//
//    // this loop waits for the answer
//    do{
//        if(Serial1.available() != 0){    // if there are data in the UART input buffer, reads it and checks for the asnwer
//            response[x] = Serial1.read();
////            Serial.print(response[x]);
//            x++;
//            if (strstr(response, expected_answer) != NULL)    // check if the desired answer (OK) is in the response of the module
//            {
//                answer = 1;
//            }
//        }
//    }while((answer == 0) && ((millis() - previous) < timeout));    // Waits for the asnwer with time out
//
//    return answer;
//}

// Calculating checksum. Function provided in SPS30 datasheet
byte CalcCrc(byte data[2]) {
  byte crc = 0xFF;
  for(int i = 0; i < 2; i++) {
    crc ^= data[i];
    for(byte bit = 8; bit > 0; --bit) {
      if(crc & 0x80) {
      crc = (crc << 1) ^ 0x31u;
      } else {
        crc = (crc << 1);
       }
     }
   }
   //Serial.print("calcCrc: "); Serial.println(crc, HEX);
  return crc;
}

void SetPointer(byte addr, byte P1, byte P2)
{
  Wire.beginTransmission(addr);
  Wire.write(P1);
  Wire.write(P2);
  Wire.endTransmission();
  }

void SPS30_start_measurement(){
   Wire.beginTransmission(SPS30_addr);
   
   // Start measurement (command: 0x0010)
   Wire.write(0x00);
   Wire.write(0x10);
   
   // Read measurement (command: 0x0300)
   Wire.write(0x03);
   Wire.write(0x00);
   
   // Send checksum
   uint8_t data[2]={0x03, 0x00};
   Wire.write(CalcCrc(data));
   
   Wire.endTransmission();
   delay(1000);
}

void SPS30_cleaning(){
  Serial.println(F("Attempting to clean SPS30 sensor..."));
  //Start fan cleaning
  SetPointer(SPS30_addr, 0x56, 0x07);
  delay(12000);
  Serial.println(F("Done!"));
  delay(50); 
}
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

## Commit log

2018-08-02 Added battery status light
2018-08-27 PCB included
    [PCB-B.Cu.gbr, PCB-B.Mask.gbr, PCB-Edge.Cuts.gbr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]
2018-08-30 Added laser cut case design file
2018-09-05 Cleanup and added casing files
    [base.dxf, button_side.dxf, cable_tie_side.dxf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]
2018-09-26 Updated assembly guide
2018-12-15 Added RGB LED button support
2019-03-16 Added bp_v5 (Kenya prototype)
2019-05-27 Added airflow model and PCB design
    [PCB.kicad_pcb, PCB.sch, PS_CAD_SPS30_D1 v12.SLDPRT]
2019-09-09 Added v8 with VOC sensor support
2019-09-19 Gerber file v8
    [PCB-B.Cu.gbr, PCB-B.Mask.gbr, PCB-Edge.Cuts.gbr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]
2019-09-19 Added PCB and pinout v8
    [PCB.kicad_pcb, PCB.sch]
2019-11-23 Added files for Nairobi distribution
    [Versatil_Nairobi_curve2.stl]
2020-01-09 Add photo of functional board without the case
    SGP30 VOC sensor ordered from here: https://bit.ly/2ssk7yA
    Pins on SGP30 as delivered face in the opposite direction and so were
    desoldered and resoldered after 180 degrees rotation.
2020-02-03 Updated cases for PCB v9
    [v0_Versatil_Nairobi_curve2.stl, v1_Versatil_Nairobi_PM_under_Tsensor_flat_2.stl, v2_Versatil_Nairobi_PM_under_Tsensor_flat_battery_screw_3.stl]
2020-02-08 Wiki reactivated
    [v0_Versatil_Nairobi_curve2.stl]
2020-03-09 Added cowbell_v3
    [bottom.stl, lid.stl, shell.stl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]
2020-03-11 Fixed error in v8 regarding file headers
    [v0_Versatil_Nairobi_curve2.stl]
2020-03-11 Fixed same error in v9
    [bp_v9.ino]
2020-04-08 Print an error message when can't write to file
    If we can't write to the file to write the initial header than print out to the serial console to make the log output clearer.
2020-05-15 Shifted things around
    [v0_Versatil_Nairobi_curve2.stl]
2020-05-17 GPS fix in v9
    [bp_v9.ino]
2020-06-09 Fixed issue with SGP values becoming negative
    [BOM.xlsx]
2020-07-22 Added 3d printed airflow
    [sps30housing-withsps30 v1.f3z, sps30housing.stl]
2020-12-04 Cleanup and rearrangements
    [BOM.xlsx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]
2021-06-02 Updated documentation
    [a_sense_board_side_final_3005_final_v6.dwg, v1_Versatil_Nairobi_PM_under_Tsensor_flat_2.stl, v2_Versatil_Nairobi_PM_under_Tsensor_flat_battery_screw_3.stl]
